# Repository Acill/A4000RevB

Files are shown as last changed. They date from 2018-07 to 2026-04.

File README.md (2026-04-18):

# A4000 Replica Project (Based on the Rev B)
Amiga 4000 Replica project. Based on the A4000 Rev B and organized by Paul Rezendes and the generous contributions of the Amiga Community. 

*** IF YOU WISH TO PRODUCE YOUR OWN BOARDS PLEASE USE THE NEW GERBERS LOCATED HERE: https://github.com/Acill/A4000RevB/tree/master/Gerbers-JLCPCB ***

ASCII (PADS) export has been added are are located into the ASCII folder. You can use this to import into other EDA applications. 

By popular request I have added the project into Kicad. its available in the Kicad folder. Please commit any change back here and document them. 

IF YOU PRODUCE BOARDS USING ORIGINAL PROJECT FILES YOU ***MUST*** TELL THE FACTORY TO IMPORT THE GERBERS AS A ***MENTOR PADS FORMAT PROJECT*** The gerbers located here are already good for use as JLCPCB. please read firther information in the gerber section. 

***Thank you Chucky for the locator build hosting! I recomend all go here during your builds for some great help!
A4000 Locator Site: http://locator.reamiga.info/locator.php?project=A4000***

***A4000 Build Guide, Thanks to Chucky! https://wordpress.hertell.nu/?p=1053***

***Shred made a great repo for an updated BOM. Thank you! Please visit the new BOM here: https://shred.github.io/a4000-bom/***

READ THIS: New board files and gerbers have been created and posted to the Github project page. A minor error was discovered that had solder mask covering the ground pads for the support bracket on the mouse and joystick ports. Previous boards work just fine and are not in danger of not working. This is more of a cosmetic update than anything else. Get the new file in the Gerber folder. When using the Chinese sites like JLPCB and PCBway you will need to upload the complete zip gerber archive and email them about the board design. It is done in Mentor PADs. This is a professional layout and it will not usually work with the automatic software they use. I have produced these here in the US and have no problems. Others have used JLPCB with no problems as well. I f you would like a single board and need help I can order sets of 5 and would be happy to sell you one. You can email me through the contact page or directly at info@acill.com and request one. Currently they run $95 shipped in the USA and $110 international.  

# Images
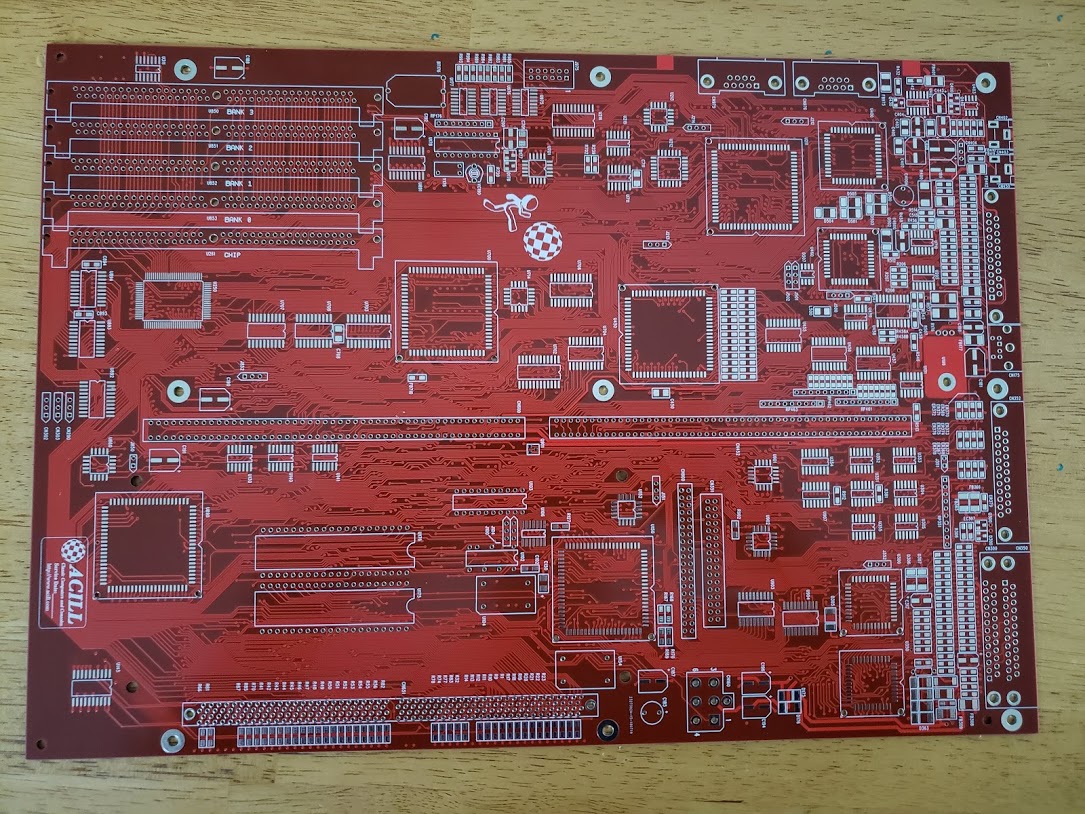
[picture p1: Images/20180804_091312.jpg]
 
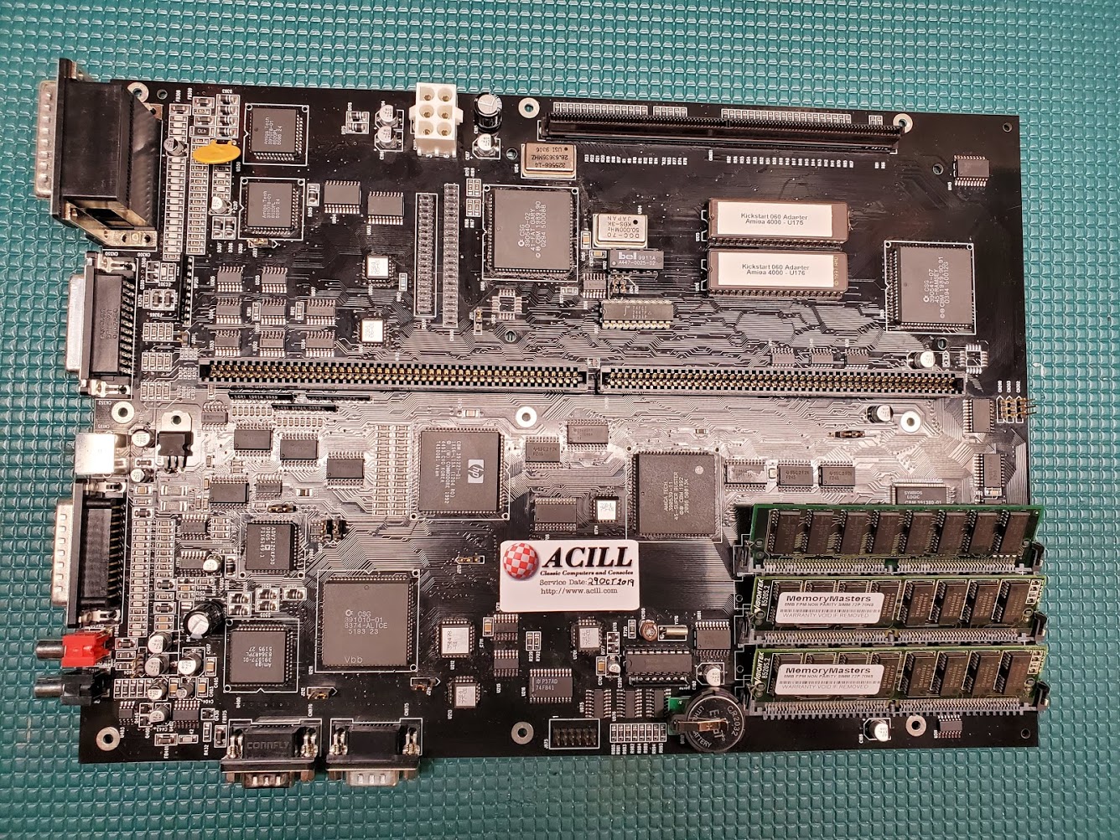
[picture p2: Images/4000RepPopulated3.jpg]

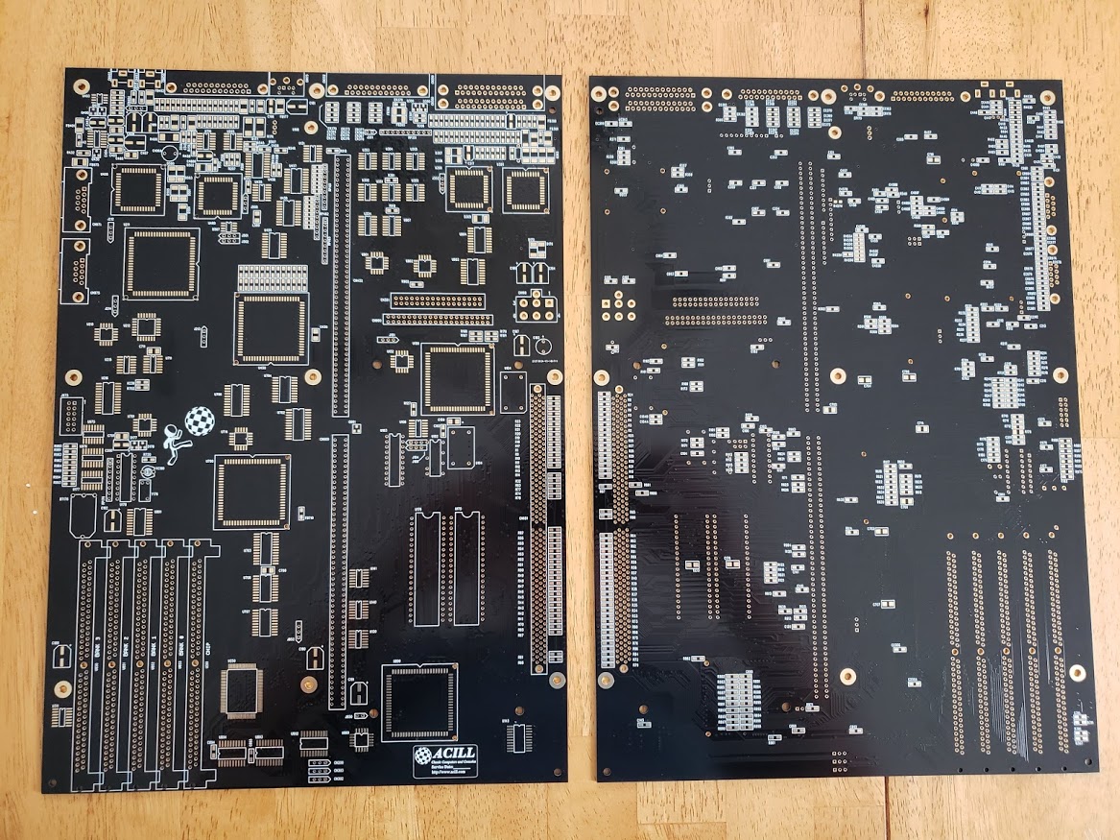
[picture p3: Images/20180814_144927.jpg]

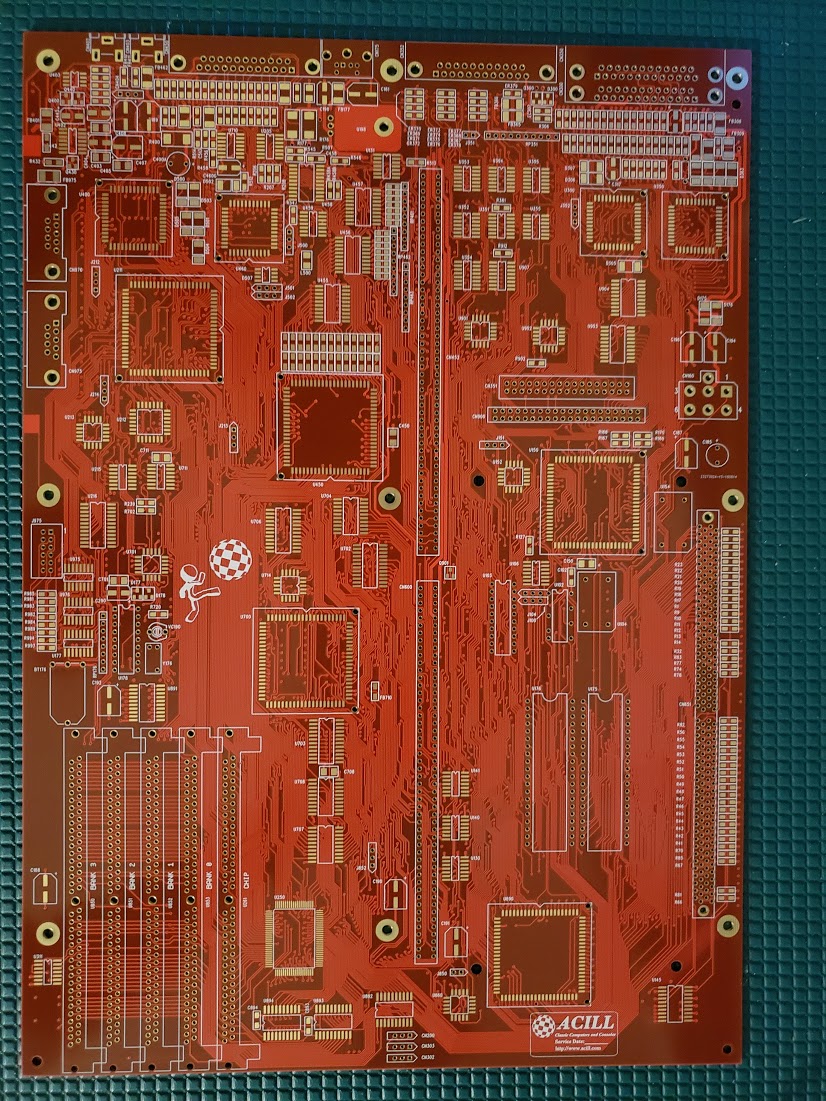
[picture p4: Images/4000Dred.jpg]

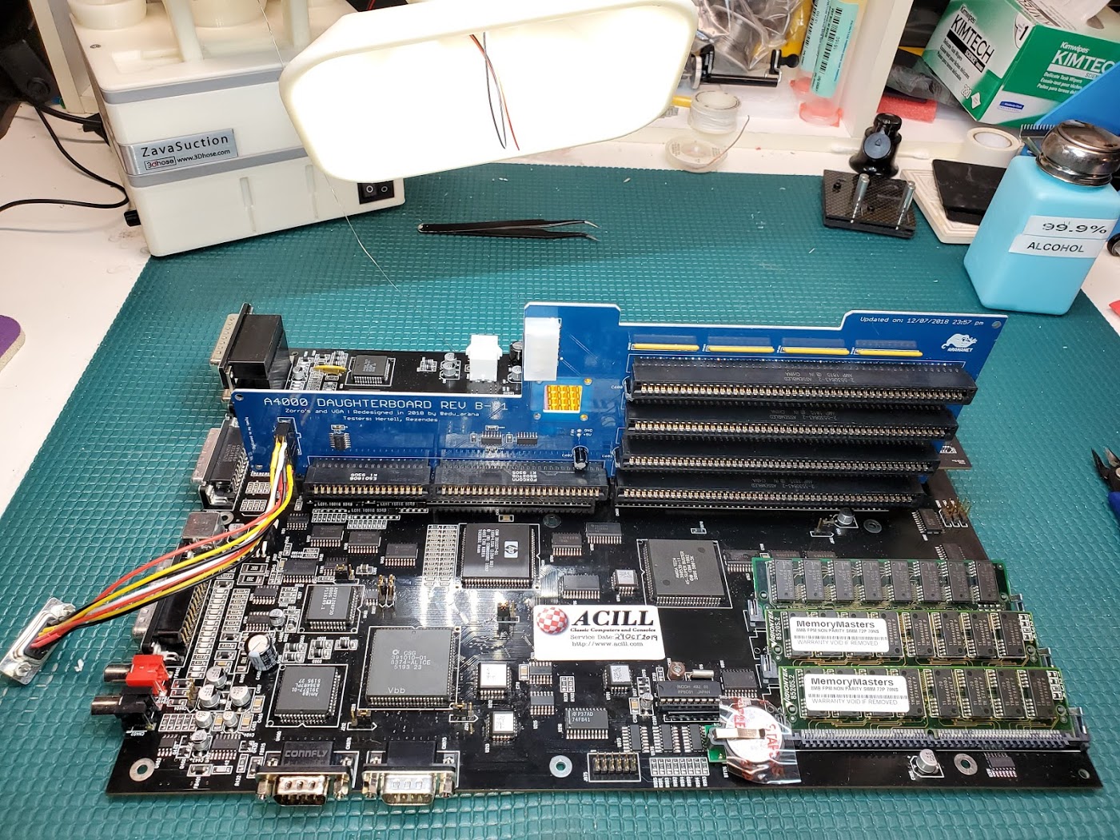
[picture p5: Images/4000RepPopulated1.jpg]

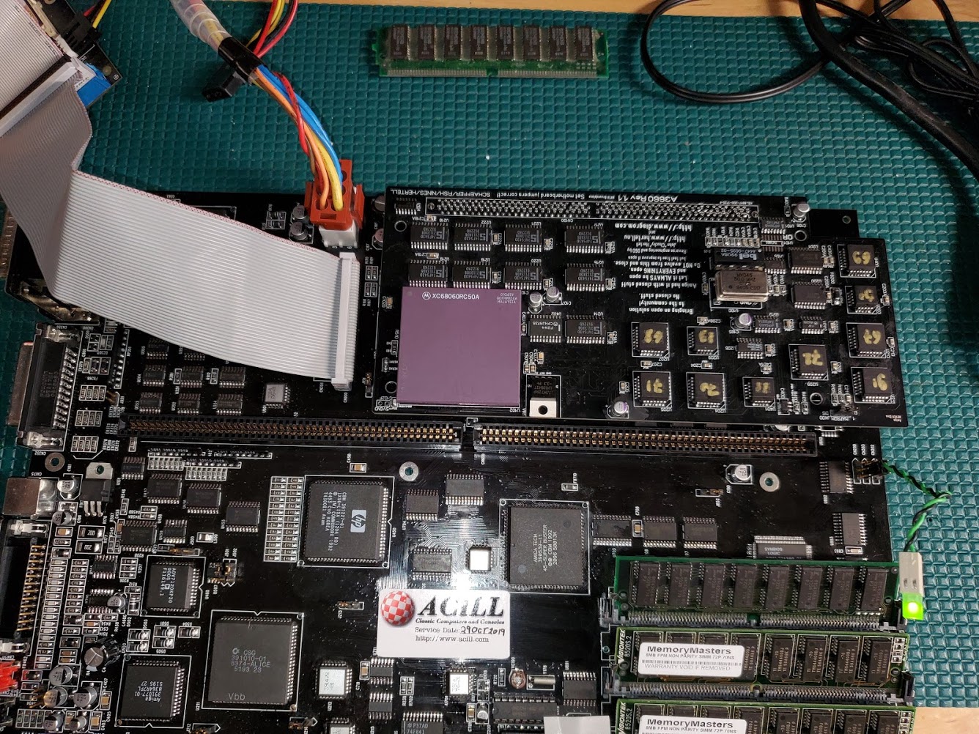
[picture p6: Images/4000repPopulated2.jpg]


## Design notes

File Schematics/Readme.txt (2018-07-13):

This is the final schematic without the electrical comparison test.
I fix the flag problems and found a few other problems that I have also fixed.  I have very high confidence in the schematic and netlist at this time. 
Schematic matches the PDF which also now matches the PCB.  There were some errors in the provided PCB.
There are 3 nets which are not connected, IO_CH_RDY, _LDS and _UDS.

I did not make any changes from the original design such as tying the unused logic gate inputs to ground.

FYI, this is a 4 layer board with mixed signal / planes for the inner layers.  They originally used the internal layers to make some of the signal connections in addition to power and ground planes.

Viewing requires Mentor Graphics PADS or the PADS free viewer! Final versions will be posted once the review is complete. 
THIS IS NOT A FEATURE REQUEST REVIEW! This is only to finalize the schematic for final board layout.

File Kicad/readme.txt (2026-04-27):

Its been a long over due wait, but here is the project in Kicad at last. Please continue to merge here and comment any updates. 

Project and schematics are together in the 7zip archive.

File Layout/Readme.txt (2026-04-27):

This is a Mentor Graphics PADs layout! If you want to use something else the ASCII exports are located in the ASCII folder. You can import them into for example Kicad or Altium. 

FINAL layout is attached PADS PCB database.
The design has been updated and follows the schematic netlist exactly.
To view the plane data go to 'Tools' and then the 'Pour Manager', 'Plane Connect' and pour all. 

This is similar to the original trace routing but I update to be more manufacturable.
The best I could do in regards to design rules, is with the majority of the board at 10mil traces and 8mil space.  Power and ground at 20mil.
Some areas have 6 mil spacing and 8 mil lines.
Unfortunately this was a poorly designed board in terms of maufacturability.  It should have been a 6 layer board.
The biggest issue is with the trace routing and trying to fit the large number of signal connections on only 2 layers.  
The original designers put traces between the pads of the SM resistors and capacitors, not generally a good idea.
Trace entry to pads was very poor with lots of 'acid traps'.
There were a few dead traces and extra vias.  At some point some of the vias may have been used as test points(?).

At least it is better than the original at this point.  I did not move the parts but cleaned the traces and changed via types.
I you want to make the board to IPC specifications at some point,  we would need to go to 6 layers and redefine most of the SM parts.

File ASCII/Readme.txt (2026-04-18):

PADS ASCII export. You can use this to import into other EDA applications such as Kicad, Altium and Easy EDA.

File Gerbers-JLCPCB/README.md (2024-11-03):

# Gerber Files with the New Silkscreens
Original Gerber files were created Using Mentor PADS application. When imported to most PCB production house websites, like JLCPCB.com, several layers are not shown correctly and will not be aligned to each other. I had a set of PCBs produced at JLC. They made the necessary adjustments and produced the boards correctly. As part of the process, they provided adjusted Gerber files. Those files are shown correctly when opened by any Gerber viewer. I imported those files into Kicad and completely redid the silkscreens on both sides.

Note that the Kicad files I created cannot be used to modify the copper and other production related layers as original component information is lost and all layers were converted to graphical elements.

As part of the production process, JLCPCB makes an adjustment to drill holes (slightly enlarge them). As we are using adjusted files, they should not do another adjustment on them. Make sure to add the note below as part of PCB remarks.

PCB Remark:
Drill layer was already compensated and optimized. Do not further modify drill layer values.

# Updated Pick and Place Files
I updated the BOM and CPL files to fix placement and rotation issues. Some of the parts are not available in JLCPCB stocks and must be ordered via Global Parts service. These orders usually take 2-3 weeks to arrive to your inventory at JLCPCB. Some parts are too expensive or not available even from GP service partners. These parts are not listed in the BOM file but they are still listed in the CPL file in case you wish to get them populated. As a result, when importing BOM/CPL files, you will get a warning about some missing parts in BOM file. Just accept and continue.

U700 (Super Buster) and U714 (GAL) sockets cannot be assembled at the same time as they have a slight conflict. I chose to get U700 socket populated by JLCPCB and slightly shave and hand solder U714 socket.

Some of the PLCC sockets show location pins when there is no hole for them on the PCB. JLCPCB PCBA team will ask you whether they should cut the pins of the PLCC socket at a cost. The part numbers I have in the BOM do not have those location pins, so there is nothing to cut. Give them this response and you will be fine. There is a PCBA remark box when ordering, but they ignored and asked me anyway.

PCBA Remark:
SMD PLCC sockets used in this project do not have placement pins. Ignore the holes or hole markers on the PCB for PLCC sockets and use pin 1 indicator on the silkscreen for the orientation of the sockets.

Kavanoz, May 2024

Preview of new Gerbers

Gerber-Viewer-Top

Gerber-Viewer-Bottom

Actual assembled PCB as produced by JLCPCB (There have been a slight update on the silkscreens after these were ordered)
Acill A4000D-Kavanoz-Top

Acill A4000D-Kavanoz-Bottom

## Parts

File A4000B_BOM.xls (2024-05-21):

BOM OCR and corrections by tbtorro (Jozsef Vamosi) based on A4000 Service Addendum
PCB Assembly, A4000D (364837 Rev B)
364837-01 | PCB Assembly, A4000 NTSC
364837-02 | PCB Assembly, A4000 PAL
364836-01 | Schematic
364838-01 | PCB Fab
364839-01 | Artwork
 | CAPACITORS |  | Package | No. Of parts
390818-01 | Capacitor, SM, MLC, NPO, 22pF (1206) | C485 C179 |  | 2
390818-04 | Capacitor, SM, MLC, NPO, 47pF (1206) | EC976-EC989 EC350-EC364 |  | 29
390818-05 | Capacitor, SM, MLC, NPO, 56pF (1206) | C178 |  | 1
390818-06 | Capacitor, SM, MLC, NPO, 100pF (1206) | EC182-EC184 EC300-EC309 EC365-EC379 EC410 EC411 EC451-EC464 |  | 44
390818-10 | Capacitor, SM, MLC, NPO, 330pF (1206) | C446, C447 |  | 2
390853-08 | Capacitor, SM, MLC, X7R, 3900pF (1206) | C432 C442 |  | 2
390853-09 | Capacitor, SM, MLC, X7R, 6800pF (1206) | C431 C441 |  | 2
390853-01 | Capacitor, SM, MLC, X7R, .01 uF (1206) | C104 C154B C186 C193 C195 C409 C460D C460E C460F |  | 9
390853-04 | Capacitor, SM, MLC, X7R, .047uF (1206) | C411-C414 C430 C440 |  | 6
310027-02 | Capacitor, SM, Ceramic, 0.1uF (1206) | C102 C103 C106 C130 C131 C140 C141 C145 C152 C154A C177 C201 C205 C211A C211B C211C C212 C213 C215 C216 C250A C250C C300 C305 C311 C350-C355 C400B C402A C402B C455-C459 C460A C460B C460C C500 C860 C890-C894 C901-C904 C907 C975 C976 C990 C511-C513 C455B C456B C457B C458B |  | 64
390797-02 | Capacitor, SM, Ceramic, Z5U, .22uF (1210) | C150 C175 C176 C199 C403 C405 C406 C450 C700-C704 C706-C708 C710 C711 C714 |  | 19
391097-06 | Capacitor, SM, Elec. Alum. 4.7uF 25V 'A' | C200 C404 |  | 2
391097-07 | Capacitor, SM, Elec. Alum. 10uF 25V 'C' | C460G |  | 1
391097-03 | Capacitor, SM, Elec. Alum. 22uF 16V 'C' | C198 C317 C318 C433 C443 |  | 5
391097-04 | Capacitor, SM, Elec. Alum. 47uF 16V 'D' | C187-C192 C194 C196 C407 C408 |  | 10
391097-01 | Capacitor, SM, Elec. Alum. 100uF 6.3V 'D' | C181 |  | 1
390101-03 | Capacitor, Elec. Alum. Radial 470uF 16V | C185 C400A |  | 2
251029-06 | Capacitor, Trimmer, Ceramic, 6.8-45pF | VC190 |  | 1
 | TRANSISTORS, DIODES, FER RITES
391121-01 | IC, SMD, NPN, Transistor, 2N3904 (SOT23) | Q300 Q901 |  | 2
391122-01 | IC, SMD, PNP, Transistor, 2N3906 (SOT23) | Q400 |  | 1
391145-01 | Transistor, SM, N-Channel JFET MMBF102L | Q430 Q440 |  | 2
391327-01 | Diode, SM, 1N4001 (MELF) | D175 D176 D305-D307 D360-D363, D500-D505 |  | 15
391129-01 | Diode, SMT, 1 N4148 (SOT23) | D177 D178 D300 |  | 3
391559-01 | Filter, Ferrite, SMT (1812) | FB177 FB308 FB309 FB364-FB366 FB401 FB462 FB463 FB464 FB476 FB478-FB480 FB975 |  | 15
391092-03 | Fitter, Ferrite, SMT (1206) | FB710 FB410 FB411 ER976-ER989 |  | 17
 | RESISTORS
391093-01 | Resistor, SM, 1W, 5%, 1 Ohm (2512) | R400 |  | 1
391093-07 | Resistor, SM, 1W, 5%, 20 Ohm (2512) | R176 R177 |  | 2
391093-04 | Resistor, SM, 1W, 5%, 47 Ohm (2512) | R383 |  | 1
310026-45 | Resistor, Chip, 1/8W, 5%, 1 Ohm (1206) | R403 R404 R465 |  | 3
310026-24 | Resistor, Chip, 1/8W, 5%, 120 Ohm (1206) | R311 |  | 1
310026-43 | Resistor, Chip, 1/8W, 5%, 33 Ohm (1206) | R104 R211 R231-R237 R240-R248 R881-R899 |  | 37
310026-01 | Resistor, Chip, 1/8W, 5%, 47 Ohm (1206) | R101-R103 R105 R106 R111 R112 R161 R162 R212-R218 R222 R223 R451 R458-R464 R500-R508 R513 R520-R543 R701-R704 ER175 R458A R458B R660 R661 ER176 ER300-ER307 ER350-ER363 ER367-ER379 ER453 ER458-ER461 ER475 R165-R170 |  | 117
391509-04 | Resistor, Chip, 1/10W, 5%, 47 Ohm (0805) | R455A, R455B R455C R455D R455E R455F R455G R455H R456A R456B R456C R456D R456E R456F R456G R456H R457A R457B R457C R457D R457E R457F R457G R457H |  | 24
310026-29 | Resistor Chip, 1/8W, 5%, 75 Ohm (1206) | R510-R512 |  | 3
310026-30 | Resistor, Chip, 1/8W, 5%, 220 Ohm (1206) | R301 R307 |  | 2
310026-21 | Resistor, Chip, 1/8W, 5%, 470 Ohm (1206) | R120-R122 R175 R178 R651 |  | 6
310026-56 | Resistor, Chip, 1/8W, 5%, 680 Ohm (1206) | R65 R66 |  | 2
310026-57 | Resistor, Chip, 1/8W, 5%, 750 Ohm (1206) | R430 R440 |  | 2
310026-07 | Resistor, Chip, 1/8W, 5%, 1.0K Ohm (1206) | R67 R68 R70-R73 R125-R128 R171-R173 R181 R182 R239 R249 R302 R371 R381 R382 R401 R402 R433 R434 R443 R444 R545-R548 R612-R626 R630-R635 R639 R708-R712 R720-R722 R861 R862 R911 R912 R975 |  | 66
310026-54 | Resistor, Chip, 1/8W, 5%, 1.2K Ohm (1206) | R79-R88 R179 R405 |  | 12
310026-51 | Resistor, Chip, 1/8W, 5%, 2.4K Ohm (1206) | R403D R403H |  | 2
310026-16 | Resistor, Chip, 1/8W, 5%, 2.7K Ohm (1206) | R1-R64 R74-R78 R206 R207 R407 R652 R871 R904 R905 |  | 76
310026-46 | Resistor, Chip, 1/8W, 5%, 3.3K Ohm (1206) | R151 R360 R361 |  | 3
310026-08 | Resistor, Chip, 1/8W, 5%, 4.7K Ohm (1206) | R515 R403C R403G R981-R994 |  | 17
310026-17 | Resistor, Chip, 1/8W, 5%, 10 K Ohm (1206) | R208 R305 R306 R406 R408 R431 R432 R441 R442 R457 R465 R514 R403A R403B R403E R403F R355-R359 |  | 21
310026-55 | Resistor, Chip, 1/8W, 5%, 11 K Ohm (1206) | R902 R903 |  | 2
310026-31 | Resistor, Chip, 1/8W, 5%, 100K Ohm (1206) | R180 |  | 1
310026-19 | Resistor, Chip, 1/8W, 5%, 470K Ohm (1206) | R435 R445 |  | 2
391154-27 | Resistor, Chip, 1/8W, 1%, 562 Ohm (1206) | R509 |  | 1
902412-14 | Res. Netwk., SIP, 9 Pin, 8 Element, 1K Ohm | RP461-RP463 |  | 3
902410-10 | Res. Netwk., SIP, 10 Pin, 9 Element, 1K Ohm | RP351 |  | 1
902442-35 | Res. Netwk., SIP, 8 Pin, 7 Element, 10K Ohm | RP176 |  | 1
325566-27 | Oscillator, 50 MHz, T.H. Can | U104 |  | 1
325566-14 | Oscillator, 28.63636 MHz, T.H. can | U154 (NTSC)
252344-01 | Oscillator, 28.37516 MHz, T.H.can | U154 (PAL) |  | 1
900560-01 | Crystal, 32.768 KHz, T.H. | Y176 |  | 1
 | INTEGRATED CIRCUITS
391513-02 | IC, Kickstart ROM (LOW) 150ns | U176 Set J151 = Pins 2-3 (V39.106) | DIP40 | 1
391514-02 | IC, Kickstart ROM (HIGH) 150ns | U175 Set J151 = Pins 2-3 (V39.106) | DIP40 | 1
391010-01 | IC, CSG, 8374, ALICE | U211 | PLCC84 | 1
391227-01 | IC, CSG, 4203, LISA | U450 | PLCC84 | 1
391077-01 | IC, 8364R7 PAULA | U400 | PLCC52 | 1
391078-02 | IC, SM, LSI, CIA 8520A-1 | U300 U350 | PLCC44 | 2
390525-01 | IC, Ricoh, Real Time Clock, RP5C01 | U178 | DIP18 | 1
391494-01 | IC, VideoDAC, Triple 8-BIT, ADV7120 | U460 | PLCC44 | 1
390540-02 | IC, LSI, FAT GARY, FOO8B | U150 | PLCC84 | 1
390541-07 | IC, FAT RAMSEY, F012G | U890 | PLCC84 | 1
391380-01 | IC, BRIDGETTE | U250 | PQFP100 | 1
390539-09 | IC, LSI, FAT BUSTER, F0131 | U700 | PLCC84 | 1
391473-01 | IC, SMD, Op Amp, Dual, LM833 | U403 | SOIC8N | 1
391103-01 | IC, SMD, Op Amp, Quad JFET, LF347 | U402 | SOIC14N | 1
390555-01 | Delay Line, 5 Tap, 25ns | U102 | DIP14 | 1
391087-01 | IC, SMD, Quad Line Driver, 1488 SOIC | U304 | SOIC14N | 1
391086-01 | IC, SMD, Quad Line Receiver, 1489 SOIC | U305 | SOIC14N | 1
391421-01 | Voltage Reference, 1.2V, SO-8 | D507 | SOIC8N | 1
901527-03 | IC, Voltage Regulator, Fixed Output, 7905 | U198 | TO220 | 1
391554-01 | IC, Linear, LF347, EIAJ Package | Sub for PN 391103-01
391478-01 | IC, PAL 22V10-10 CAS Gen Content: 391392-03 | U212 | PLCC28 | 1
391477-01 | IC, PAL, 16L8-10 Chip RAM Ctrl Content: 391412-01 | U213 | PLCC20 | 1
391476-01 | IC, PAL, 16R4-15 Arb & int. Content: 391359-04 | U701 | PLCC20 | 1
391475-01 | IC, PAL, 16L8-10 Zorro Decode Content: 391199-03 | U714 | PLCC20 | 1
391406-01 | IC, PAL, 16L8-15 IDE Decode Content: 391199-04 | U901 | PLCC20 | 1
391405-01 | IC, PAL, 16R6-15 Programmed PLCC20, IDE state Content: 391403-02 | U902 | PLCC20 | 1
391276-01 | 7406, SOIC package | U131 | SOIC14N | 1
391188-01 | 7407, SOIC package | U311 U141 | SOIC14N | 2
391499-01 | 74F521, SOIC package | U145 | SOIC20W | 1
391088-01 | 74F04, SOIC package | U215 | SOIC14N | 1
391183-01 | 74F08, SOIC package | U130 U710 | SOIC14N | 2
391175-01 | 74F32, SOIC package | U140 | SOIC14N | 1
391320-01 | 74F74, SOIC package | U106 U459 | SOIC14N | 2
391325-01 | 74F86, SOIC package | U711 | SOIC14N | 1
391375-01 | 74F245, SOIC package | U704 U707 U708 U891-U894 | SOIC20W | 7
391481-01 | 74F841, SOIC package | U216 | SOIC24W | 1
391374-02 | 74FCT646T, SOIC package | U702 U703 U706 | SOIC24W | 3
391480-01 | 74HCT166, SOIC package | U975 U976 | SOIC16N | 2
391400-01 | 74FCT244T DIP package | U103 | DIP20 | 1
391474-01 | 74FCT245T, SOIC package | U455-U458 | SOIC20W | 4
391377-01 | 74HCT174, SOIC package | U177 U354 U907 | SOIC16N | 3
391326-01 | 74LS38, SOIC package | U352 | SOIC14N | 1
391141-01 | 74LS74A, SOIC package | U351 | SOIC14N | 1
391311-01 | 74HC4066, SOIC package | U205 | SOIC14N | 1
391100-01 | 74HCT245, SOIC package | U903 U904 | SOIC20W | 2
391191-01 | 74LS125A, SOIC package | U353 U355 | SOIC14N | 2
391548-01 | 74F86, SM, EIAJ package | Substitute for PN 391325-01
391552-01 | 74HCT174, SM, EIAJ Package | Substitute for PN 391377-01
391555-01 | 74LS74A, SM, TTL, EIAJ Package | Substitute for PN 391141-01
 | SOCKETS
390768-04 | Socket, 20 Pin .3 DIP20 machine pin | U103 |  | 1
904150-06 | Socket, 40 Pin .6 DIP40 | U175 U176 |  | 2
391368-01 | Socket, 72 Pin 22.5 Deg. SIMM | U261 U850-U853 |  | 5
390719-01 | Socket, single pin (.040 hole) or DIP14 machine pin | U104 U154 |  | 2
 | MISC ELECTRICAL
380393-02 | Battery, NICAD, Rechargeable, 3.6V | BT176 |  | 1
390924-01 | Varistor Switch, Self Resetting 1.85A | F 175 |  | 1
 | CONNECTORS
903345-06 | 12 DIL .1" x .1' Header | J975 |  | 1
903345-17 | 34 DIL .1' x .1" Header | CN351 |  | 1
903345-20 | 40 DIL .1" x .1" Header | CN900 |  | 1
903326-02 | 2 x .1" SIL | J351 J850 |  | 2
903326-03 | 3 x .1" SIL | CN404 J100 J104 J151 J212-J214 J352 J500-J502 J852 CN200 CN302 CN303 |  | 15
390242-01 | DB9 Male | CN975 CN976 |  | 2
390242-03 | DB23 Male | CN450 |  | 1
390241-03 | DB23 Female | CN352 |  | 1
390625-04 | Stacked DB25 Male/Female (missionary) | CN350+CN300 |  | 1
390851-04 | 6 Pin MINI DIN, Female | CN175 |  | 1
390043-01 | Shorting Bars (Shunts) | J100 J104 J120 J151 J152 J212 J214 J352 J850 J852 |  | 10
903349-01 | 6 Pin Connector (Power In) | CN160 |  | 1
252122-02 | RCA Jack (Red) | CN403 |  | 1
252122-01 | RCA Jack (White) | CN402 |  | 1
903446-06 | 100 Pin Edge Card Connector | CN452 CN600 |  | 2
390557-01 | 200 Pin KEL200 Female/Receptacle Conn. | CN651 |  | 1
 | BLANK COMPONENTS
 | L500
 | C406H
 | Total no. Of parts |  |  | 788
 | Number of trough hole parts about 30pcs

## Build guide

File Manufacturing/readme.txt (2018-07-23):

This is the manufacturing data needed for pick and place and other required files for various manufacturing processess. 
These are not required for most fabs to just produce boards, but is very usefull for larger scale orders if users wanted it done.

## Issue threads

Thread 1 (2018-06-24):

A4000RevB schematic feedback

mrand, 2018-06-24:
I saw the request for review and had a few minutes to fly through the schematic.  I didn't review much of the logic, so hopefully someone else is doing that.

I haven't looked at the 74F08 and HC logic datasheets in a while,  but I'd suggest tying both inputs off, not just one input of each gate (U130-A, -C, and -D).  U177.13 and .14 as well as U215-D and U907-A.   And maybe the inputs to U459-B.

And when you do, you might consider tying off all the logic gates with pull resistors so that you can more easily use that gate in case of emergency rather than dead-bugging a gate somewhere, or having to lift a pin.

Is there a way to do a cross-reference (typically used to add page numbers to off page flags)?  That would help you verify that you don't have any nets mis-named or mis-connected.

There are a few comments, including most especially on page 13, that make it seem like some follow-up work might be needed.

Nice work!

Acill, 2018-06-25:
Thanks for the comments! I have submitted this to the company doing the design work.

Acill, 2024-05-21:
Schematics are in what I feel are the final and most closely representing the final production version of the A4000. Many improvements have been done as well to clean up some silly decisions made by the original design.

Closed 2024-05-21.

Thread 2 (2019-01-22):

ADV7120 does not get 5V VAA

ishe, 2019-01-22:
I have built the A4000 with this motherboard and have noticed a serious issue. The picture on the monitor was too dark when I used the RGB signals (indeed I was lucky to see anything). It turned out that the ADV7120 does not get 5v to its VAA pins. Troubleshooting it I have noticed that L500 inductor is connected to nowhere. It seems the layout is incorrect and ADV7120 does not get 5v input! L500 should be connected to 5v and to AVID+. This is missing from the PCB so L500 is isolated and useless.

Acill, 2019-01-23:
Where did you get your board from? I have built several of these now as
well as several other people without finding this issue.

On Wed, Jan 23, 2019 at 12:30 AM Istvan Hegedus <notifications@github.com>
wrote:

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

Acill, 2019-01-23:
Where did you get the board you used from. Was it one of mine? Several people have built them now as well as the 4 I have done myself without finding this issue. All are working just fine.

ishe, 2019-01-23:
Hi,
I have bought it from you via ebay. But I am 100% sure all your boards
don't have the L500 connected to anywhere. I have checked the schematic on
Github and L500 is left unconnected in the schematic! The reason why others
did not have issue is that they have installed R465 (1 ohm). I however did
not install it at first because original boards did not have it either.
Also amigapcb.org has L500 connected to null signals. It is weird why.
Istvan

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

ishe, 2019-01-24:
I have used both locators, amigapcb.org and John Hertell's locator to build. I don't have original board to verify, but from the photos on the net what I can see is that L500 has 2 vias going to probably to vcc layer and to other side. On the photos (big book of Amiga HW) R465 is not installed. Also the BOM on github says for R465 that it is a blank component (number of 1ohm 1206 resistors is only 2). Using this motherboard L500 is useless and should be removed from BOM.
In some other forums at least one person mentions that he has 10k resistor on R465 which obviously not a good choice if there is no L500. Other person has measured voltages on L500 and it was 4.95v so I am sure on some boards L500 should be active.

Acill, 2019-01-24:
I will look more into this then.

On Thu, Jan 24, 2019 at 1:30 AM Istvan Hegedus <notifications@github.com>
wrote:

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

Acill, 2019-01-25:
Looking more into this  If you're going to fit a 1 ohm resistor at R465, then dont bother installing L500. With L500 installed you shouldnt need R465. This is shown on the original Commodore schematic as well and dont understand why they have used both, but being a clone i just followed it.

ishe, 2019-01-27:
Yes, that is true. Probably L500 was planned to filter PSU noise. It works
fine with R465 as 1 ohm. Other parts of the PCB seem to be ok. I have built
it and works fine with an A3660 CPU card!

2019. jan. 25., Pén 19:40 dátummal Acill <notifications@github.com> ezt
írta:

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

johntayloruk, 2020-06-09:
Hi, I know this is old now, but I’ve just spent the entire day trying to identify why my new build wasn’t working.  It’s only when I caught glimpse of something on screen that I turned the brightness up on my monitor that i saw a very faint display.  I’ve checked all components related to the video output and the come across this thread.

I have put the fixed inductor in L500 and a 10k resistor at R465 as per the BOM.

Are you saying I need to remove the 10k resistor at R465 and replace it with a 1 ohm resistor and it will work??  Do I need to remove the L500 top or is it ok there with the 1 ohm resistor?

ishe, 2020-06-10:
Hi,

There is no point in installing L500 to its place on the motherboard as
this replica does not have that connected at all. If you check traces it is
just a copper island, so it does not play a role.
Instead I recommend to go on the bottom of the motherboard and either
install 1 ohm to R465 or install the inductor to R465 which was supposed to
be installed on L500. I have tried both and it works fine. I have left the
inductor there.
Without these the ADV7120 does not get the 5v supply thus your screen is
very dark.

Br
Istvan

On Wed, Jun 10, 2020 at 1:24 AM johntayloruk <notifications@github.com>
wrote:

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

johntayloruk, 2020-06-10:
Just added the 1ohm resistor and it works!! Thank goodness I came across your issue, I haven't seen it mentioned anywhere else and my orig A4000 has nothing at R465.
Very happy now! :)
Thank You!

ishe, 2020-06-10:
I am glad I could help you! Your original A4000 must have L500 in its place
and that is the reason why it works without R465. On that motherboard L500
trace is connected and provides the 5v to ADV7120 via that thus R465 is not
needed there.
Best Regards
Istvan

On Wed, Jun 10, 2020 at 10:09 AM johntayloruk <notifications@github.com>
wrote:

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

Acill, 2020-06-18:
Put them 1Ohm in and see if it works.. I think it should. If not remove
L500.

On Tue, Jun 9, 2020 at 4:24 PM johntayloruk <notifications@github.com>
wrote:

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

saft6luck, 2024-02-06:
> Put them 1Ohm in and see if it works.. I think it should. If not remove L500.

So, in Jan2019 version, L500 is not connected at all. Only R465 can be used.

Acill, 2024-05-21:
New gerbers are clearly marked not to populate this component and to use a 1Ohm in place in the new silkscreen.

Closed 2024-05-21.

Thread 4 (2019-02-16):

Images

lorenko, 2019-02-16:
Can you post a fully populated hires top view? It can help for find and orienting materials.
thanks

Acill, 2020-01-13:
Done, sorry it has taken so long.

lorenko, 2020-01-13:
Thank you ;)

Acill, 2024-05-21:
New images posted in both Gerbers and main folders.

Closed 2024-05-21.

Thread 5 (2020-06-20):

Gerber problems...

JensRestemeier, 2020-06-20:
I'm not having much luck using the Gerber files.  (a4k-6x_pads_Jan2019.zip)
GERBV shows one layer (ASB) mirrored, most layers offset from each other.
The Gerber viewer in KiCad shows the top silkscreen layer offset from the rest.

I tried uploading it to a few board houses to get a quote, but they all seem to error out. Renaming the layers to the recommended names, for example from OSHPARK (https://docs.oshpark.com/troubleshooting/naming-pattern/ ) and deleting extra files still fails because of a missing board outline.

Obviously some people get boards manufactured, so is there a board house that has success with these files? Do they need to be converted somehow?

Acill, 2020-06-21:
These are in PADS format. I have been using a place in the US to do it, but
any reputable board house should have no problem with these. I have heard
even  https://jlcpcb.com/ has done them.

On Sat, Jun 20, 2020 at 3:34 PM Jens Ch. Restemeier <
notifications@github.com> wrote:

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

Acill, 2020-06-21:
Use this viewer:  https://www.pads.com/downloads/pads-pcb-viewer/

On Sun, Jun 21, 2020 at 12:21 AM Paul Rezendes <paul.rezendes@gmail.com>
wrote:

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

johntayloruk, 2020-06-21:
I’ve just had a bunch of A3660 boards made through https://jlcpcb.com/ And has no problems.  Easy to upload the gerbers and get a quote, fast build, delivery and reasonable price too.

JensRestemeier, 2020-06-21:
JLCPCB is the place I usually use for my PCBs, and I was trying to get a whole set of motherboard, daughter board and A3660 board.

The zip file from Chucky uploads fine, displays a preview and gives a quote.

The Gerber zip file from https://github.com/arananet/A4000db/tree/master/version1.2 previews fine in the KiCad Gerber viewer, but doesn't display anything or updates a quote on jlcpcb.

The Gerber zip file from https://github.com/Acill/A4000RevB/blob/master/Gerbers/a4k-6x_pads_Jan2019.zip shows misaligned layers in KiCad and Gerbv, and a mirrored layer in Gerbv. It doesn't display anything or updates the quote on jlcpcb.

I tried PCBWAY, JLCPCB and OSHPARK. OSHPARK gave me a quote for the daughter board after I renamed layers to match their naming pattern, it didn't work with the motherboard Gerbers. I didn't try any other company that requires an email registration before doing anything.

If people had success with JLCPCB in the past I'll contact their support, in case a recent software update on their side broke their import pipeline.

JensRestemeier, 2020-06-22:
I heard back from JLCPCB support, they think the upload problems are because of the file size, and they may work OK.
They pointed out that a4k-6x_pads_Jan2019.zip has no independent outline layer, is it possible to generate that in Pads?
(It makes me a bit nervous to order large boards without checking that the files uploaded correctly into the system, but if other people had success I'm willing to give it a try...)

kavanoz64, 2024-05-15:
I uploaded new Gerber and pick and place files. These work fine with JLCPCB and should work with other PCB houses too.

Closed 2020-06-21.

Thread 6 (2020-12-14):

Gerber files

AmigaPapst, 2020-12-14:
hello,

we would like to use the gerber files. But they does't work in Kicat. Can you help?

Best regards
Simon

Acill, 2020-12-14:
These gerbers are made using Mentor Graphics PADS. They work find for
manufacturing boards as long as you mention that to the board house you
use. I have had many made using them. I don't have knowledge of other CAD
software and use PADs.

-Paul

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

AmigaPapst, 2020-12-14:
Thanks for your fast reply. I have problems to view the gerber files with gerber viewer software. We see a offset of different layer. Which files are need to produce the boards?

AmigaPapst, 2020-12-14:
The top silk screen .SST has a offset of x and y coordinates compare to copper layers. The bottom silk screen .ssb fits perfectly.

AmigaPapst, 2020-12-14:
drill file (*.drd) has a y offset of 2,54 mm.

AmigaPapst, 2020-12-14:
The following layer are fits perfectly aligned on top:
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

AmigaPapst, 2020-12-14:
The following layer are doesn't fits perfectly aligned on top:
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

AmigaPapst, 2020-12-14:
They have the same problems: https://community.sw.siemens.com/s/question/0D54O00006eo69e/output-gerber-files-are-not-aligned

AmigaPapst, 2020-12-14:
This is a example manual how to export gerber files from PADS.
https://docs.oshpark.com/design-tools/mentor-graphics-pads/

Acill, 2020-12-17:
a4k-6x_pads_Jan2019.zip
<https://github.com/Acill/A4000RevB/blob/master/Gerbers/a4k-6x_pads_Jan2019.zip>
is the complete gerber you should be sending to a board house to get boards
made and tell them its in mentor Graphics PADS format.  These are from
professional board cad software, not open source like Kicad and cant be
read by them. If you want to view them you can use the PADs viewer for
free. Its located here: https://www.pads.com/downloads/pads-pcb-viewer/

You can open the project layout files for complete viewing as well. That
file is : a4k-4x_pads_FINAL.pcb
<https://github.com/Acill/A4000RevB/blob/master/Layout/a4k-4x_pads_FINAL.pcb>

Here are direct links from my github project page

Project layout file: https://github.com/Acill/A4000RevB/tree/master/Layout
Gerbers: https://github.com/Acill/A4000RevB/tree/master/Gerbers

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

Acill, 2020-12-17:
I have produced hundreds of these boards with no issues using the export
file I provided you. If you are using one from another source I cant help
you. Others have also been able to produce working boards suck as john
hertell in Sweden. Whoever you are using to make them is clearly doing
something wrong if they cant figure it out.

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

Acill, 2020-12-17:
Seems fine here?

[image: image.png]

On Thu, Dec 17, 2020 at 6:44 AM Paul Rezendes <paul.rezendes@gmail.com>
wrote:

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

AmigaPapst, 2021-01-17:
Thanks for your help. We produce the board. 👍

The-Real-G-Evil, 2022-08-06:
Hello Acill

Where did you produce your boards?

I want JLCPCB to produce them and they ask for the layer names.
Can you tell me what to select?

Regards Tim

Acill, 2022-08-06:
The auto tool won’t work. Upload the complete Berber zip and tell them the
format is mentor pads. John Hertell has used them and has no problems  with
them.

On Sat, Aug 6, 2022 at 12:43 PM The-Real-G-Evil ***@***.***>
wrote:

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

kavanoz64, 2024-05-15:
I uploaded new Gerber and pick and place files. These work fine with JLCPCB and should work with other PCB houses too.

Acill, 2024-05-15:
I just merged it. Thanks!

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

AmigaPapst, 2024-05-15:
Hello Acill,

thanks for you message and for merging. ;)

Best regards
Simon

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
Kind Regards
--
<sb>
Alinea Computer
Torsten Hees & Simon Neumann GbR
Amiga-Softwareentwicklung, Vertrieb und Online-Shop

Geschwister-Scholl-Str. 26
61273 Wehrheim
Deutschland

Tel.: +49 (0) (60 81) 5 76 99 88
(Zeiten: Mo bis Fr von 18 bis 19 Uhr, Sa von 11 bis 12 Uhr)

Internet-Seite: http://www.alinea-computer.de
Online-Shop: http://www.amiga-shop.net
Facebook: http://www.facebook.com/alineacomputer

Closed 2024-05-21.

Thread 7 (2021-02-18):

PCB Specifications?

shred, 2021-02-18:
I'm not an expert about PCB production. I tried to calculate the price at pcbway, but after uploading the Gerber files, I was confronted with questions about PCB specifications, like the number of layers, the individual layer names, thickness, min hole size, surface finish, via process, etc.

Can you give the "musts" and also some recommendations in the README that would give a good result?

Thank you!

Acill, 2021-02-18:
Its a 4 layer board and you need to email them the the zip file and tell
them its gerber output fron Mentor Graphics PADs.

-Paul

On Thu, Feb 18, 2021 at 8:56 AM Richard Körber <notifications@github.com>
wrote:

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

shred, 2021-02-18:
Even if I would send the zip file by mail, I guess they still want to know about thickness, surface finishing etc. What I mean is: It would be easier for noobs like me to produce "cheap" replica PCBs if I can just upload the ZIP file in their quick order tool, pick some options like recommended in the README, and then place the order and be done with it.

Well, I tried their Gerber viewer and ran into issue #6, so it probably won't work with pcbway anyway.

Acill, 2021-03-03:
Many people have had these made at those places with no problems. Its all
standard specs. Finish is up to you, most recommend Enig. If you use a PCB
viewer use the free one from Mentor PADS.

On Thu, Feb 18, 2021 at 10:25 AM Richard Körber <notifications@github.com>
wrote:

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

Acill, 2021-03-03:
Here is an order from JLPCB I made to see how they worked out. The boards
are not bad from them, but I honestly dont trust the China fabs.
[image: image.png]

MAybe if you email them and give them this order number Order Number:
Y5-2327302A you can get them to make them. I ordered 5 boards and it cost
me $360, so its still not cheap with the shipping.

On Wed, Mar 3, 2021 at 6:54 AM Paul Rezendes <paul.rezendes@gmail.com>
wrote:

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

shred, 2021-03-16:
Thank you for your help! Yes, it's not cheap. As I don't know much about PCB making, it was too risky for me to get five nice wall decorations because I made a mistake somewhere. I found a reseller of your PCB, so I just ordered one in the meantime.

However it's good that it is now documented somewhere.

Closed 2021-03-16.

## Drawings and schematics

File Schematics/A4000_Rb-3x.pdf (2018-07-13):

# A4000 Rb

# CLOCKS AND LOGIC

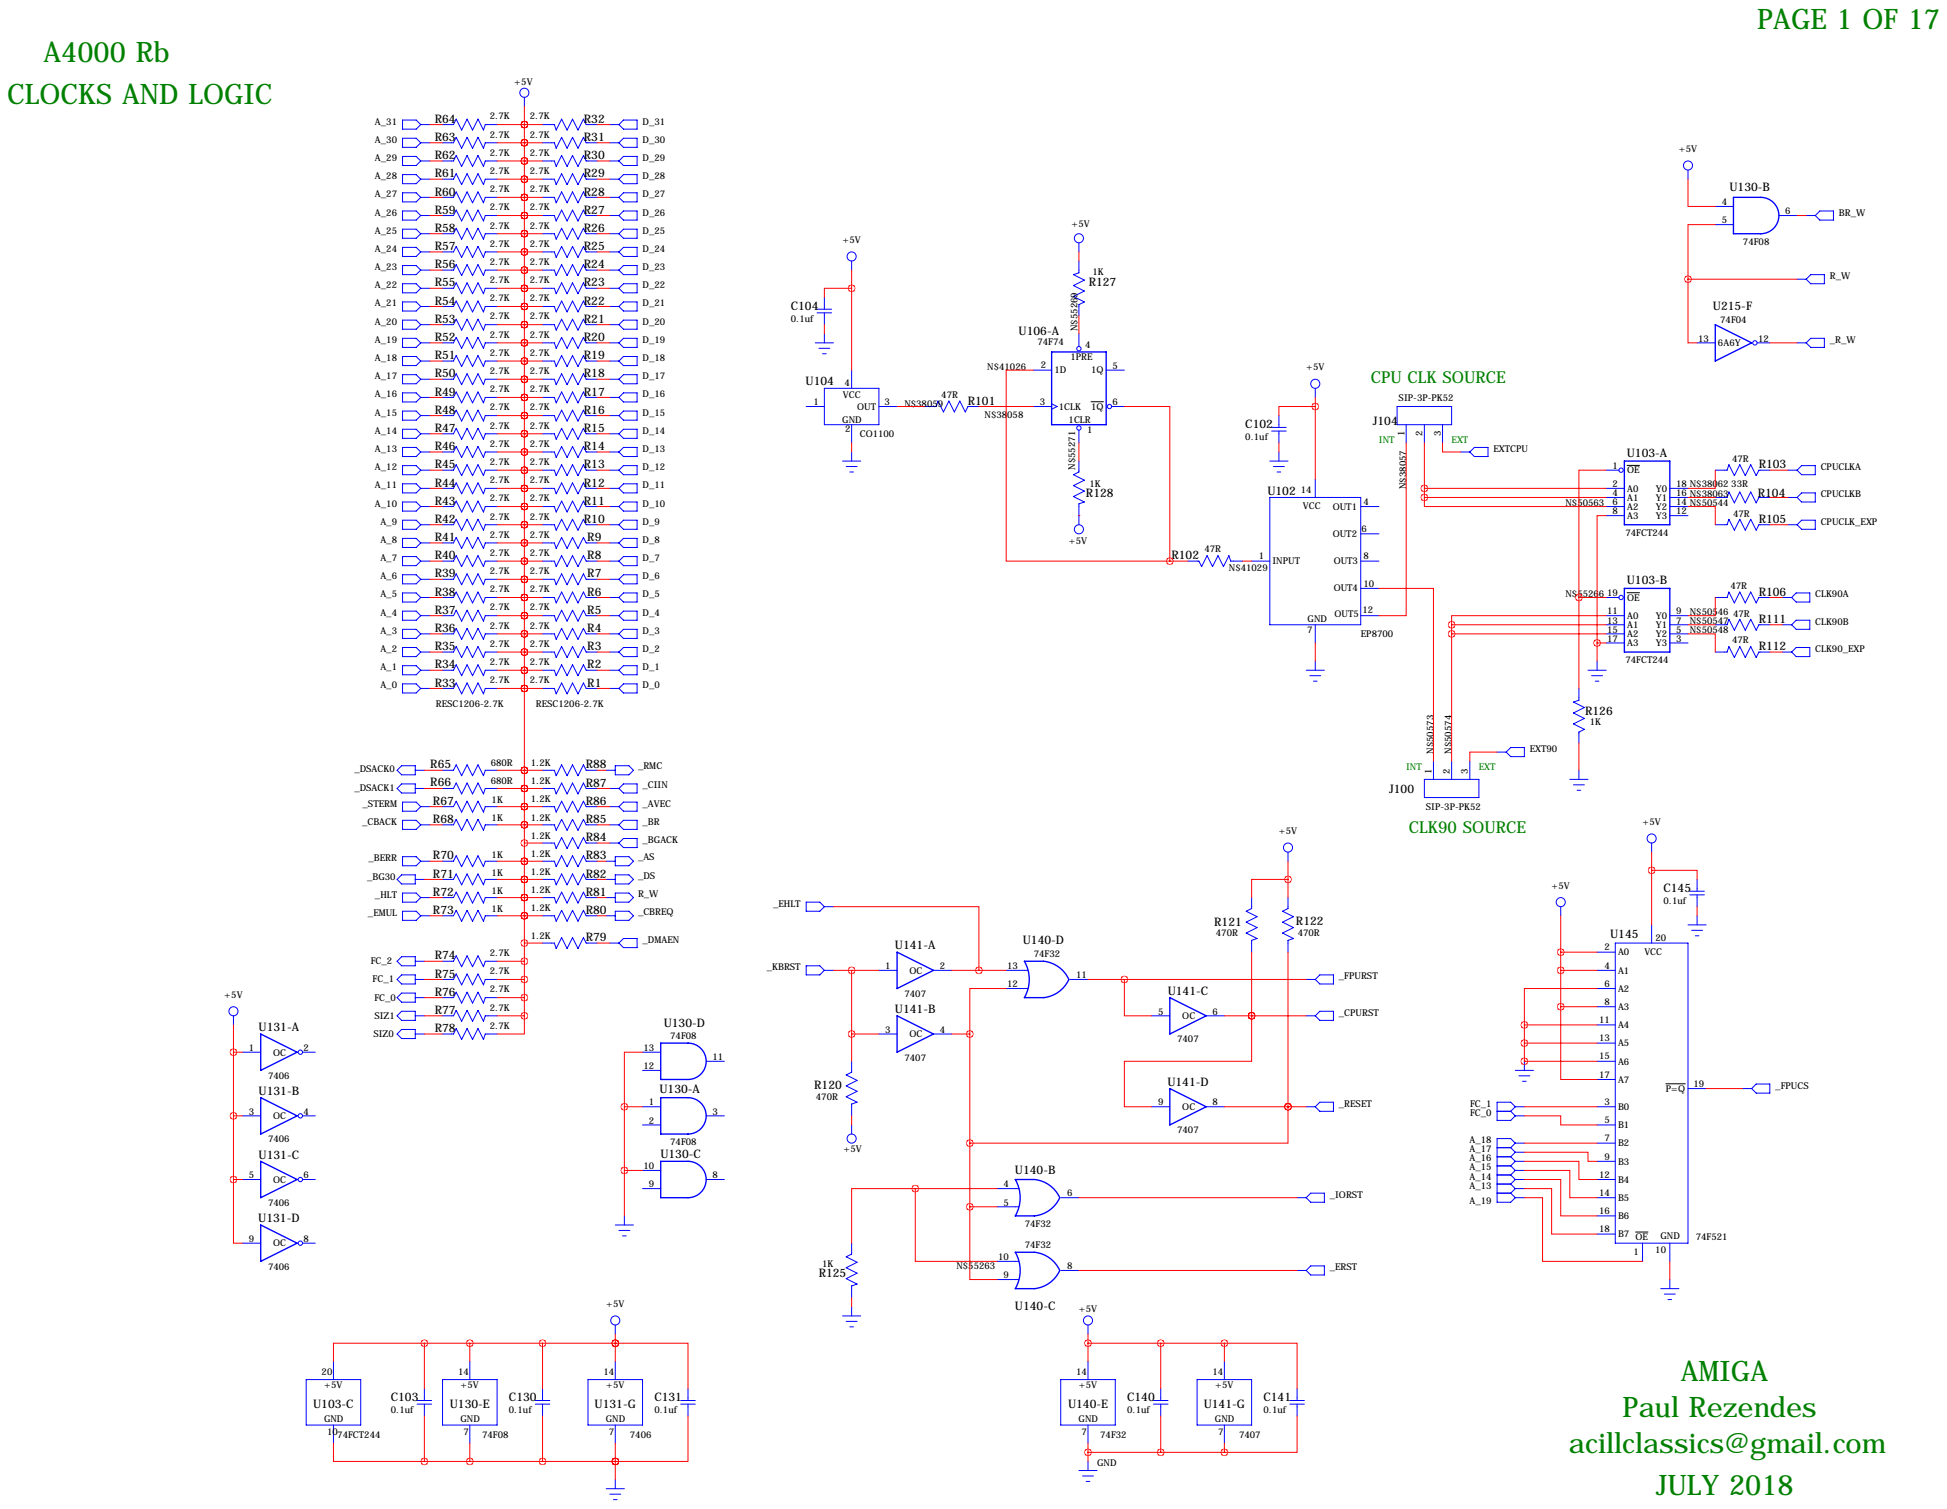
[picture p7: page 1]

# FAT GARY, ROM

U106-B

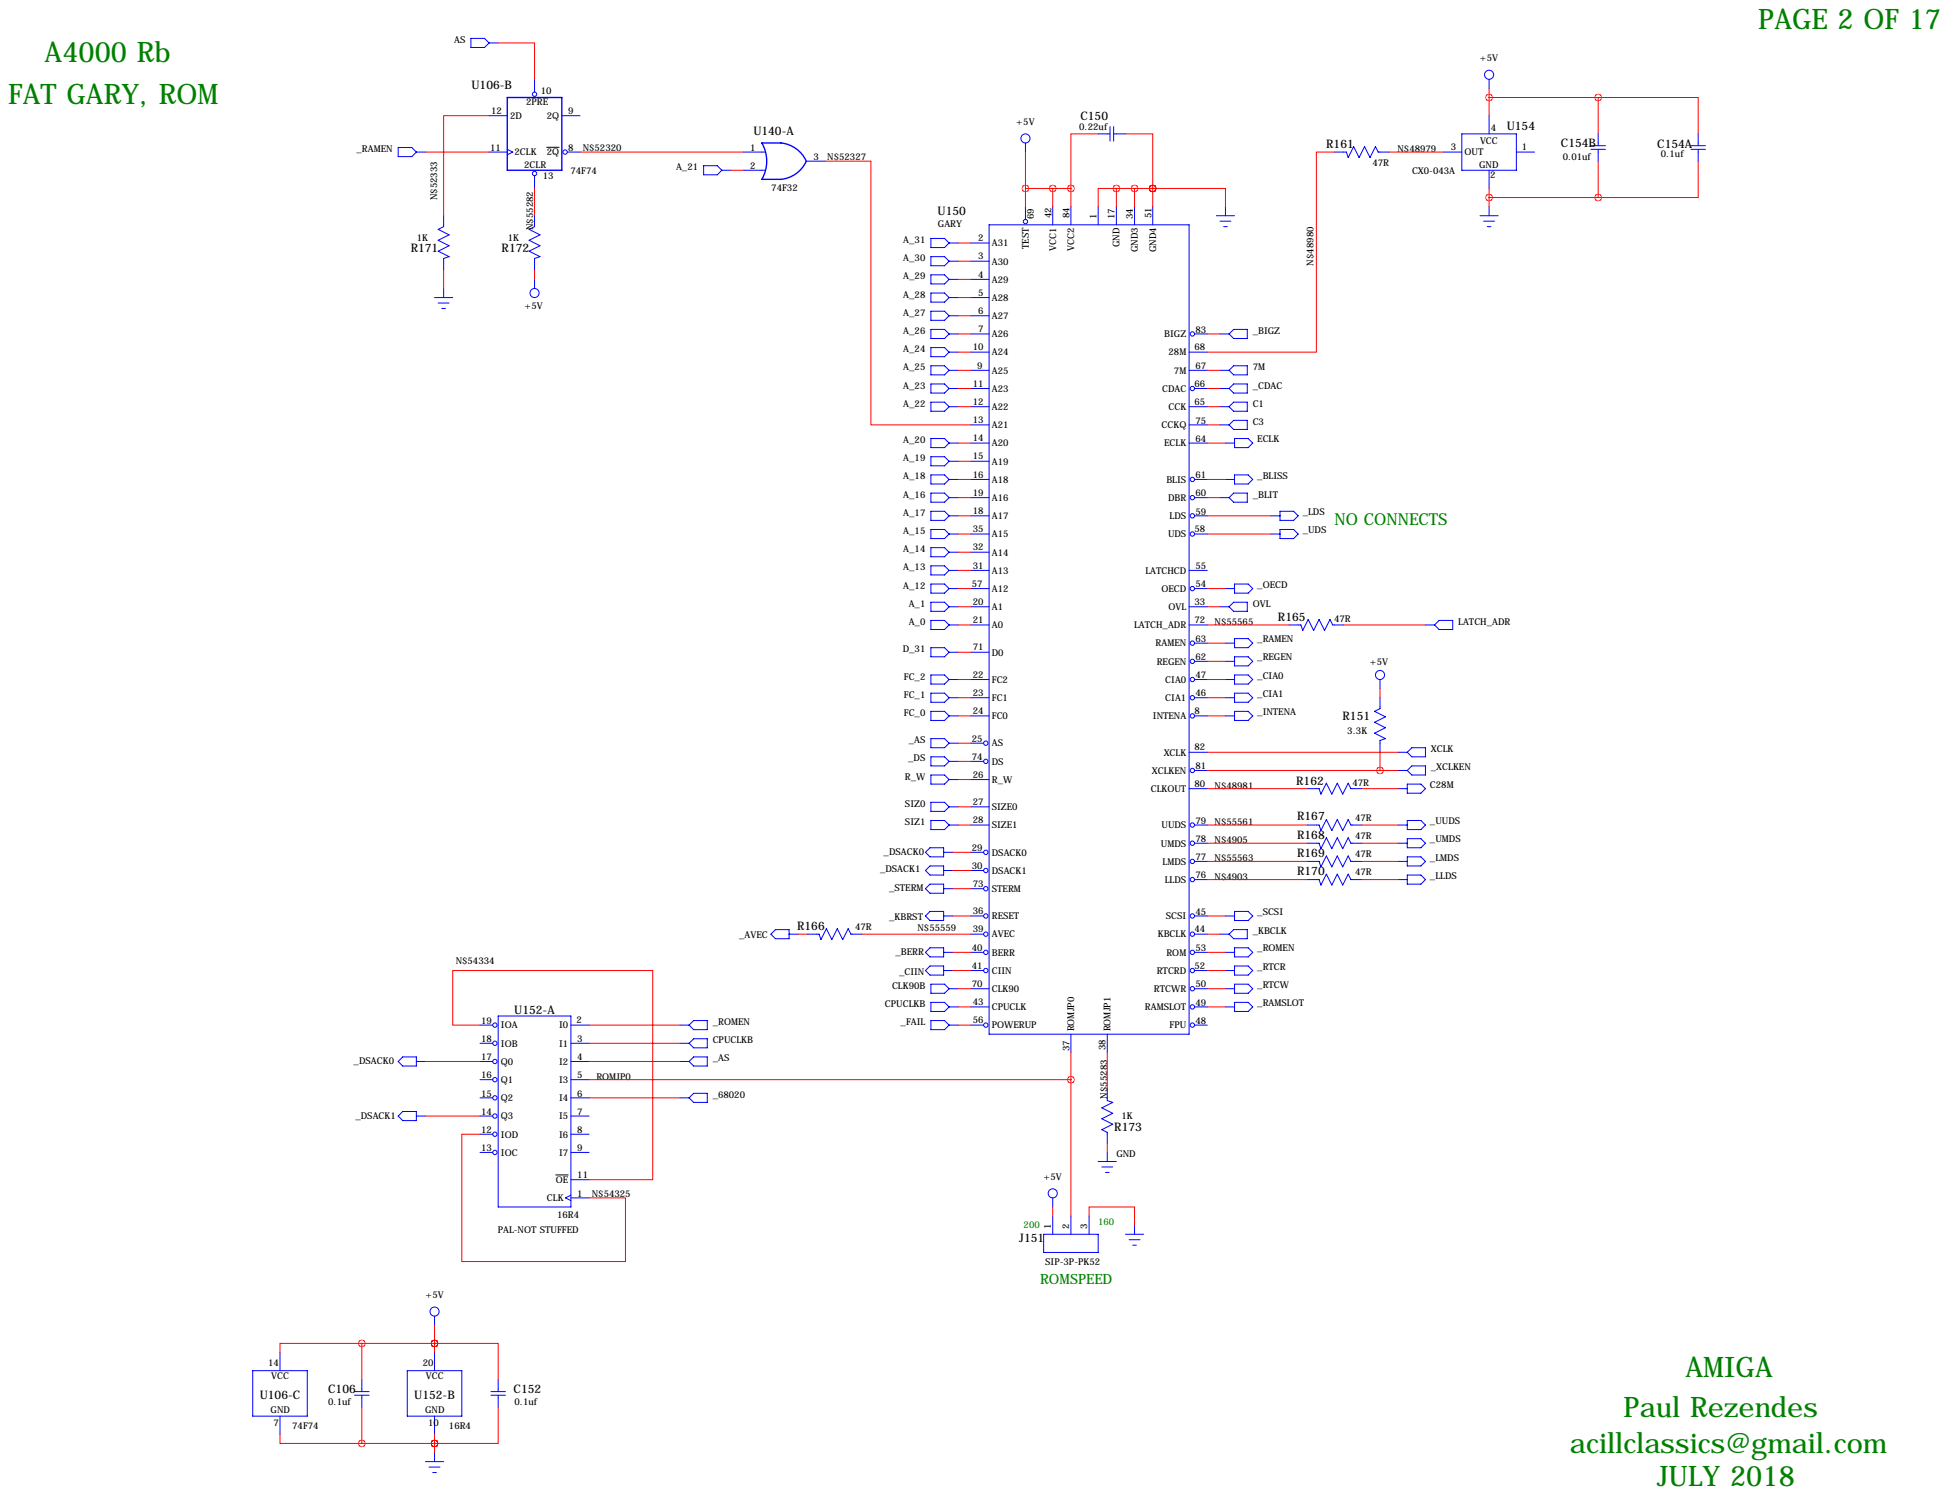
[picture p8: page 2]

# ROMs, RTC, keyboard, power in

R178

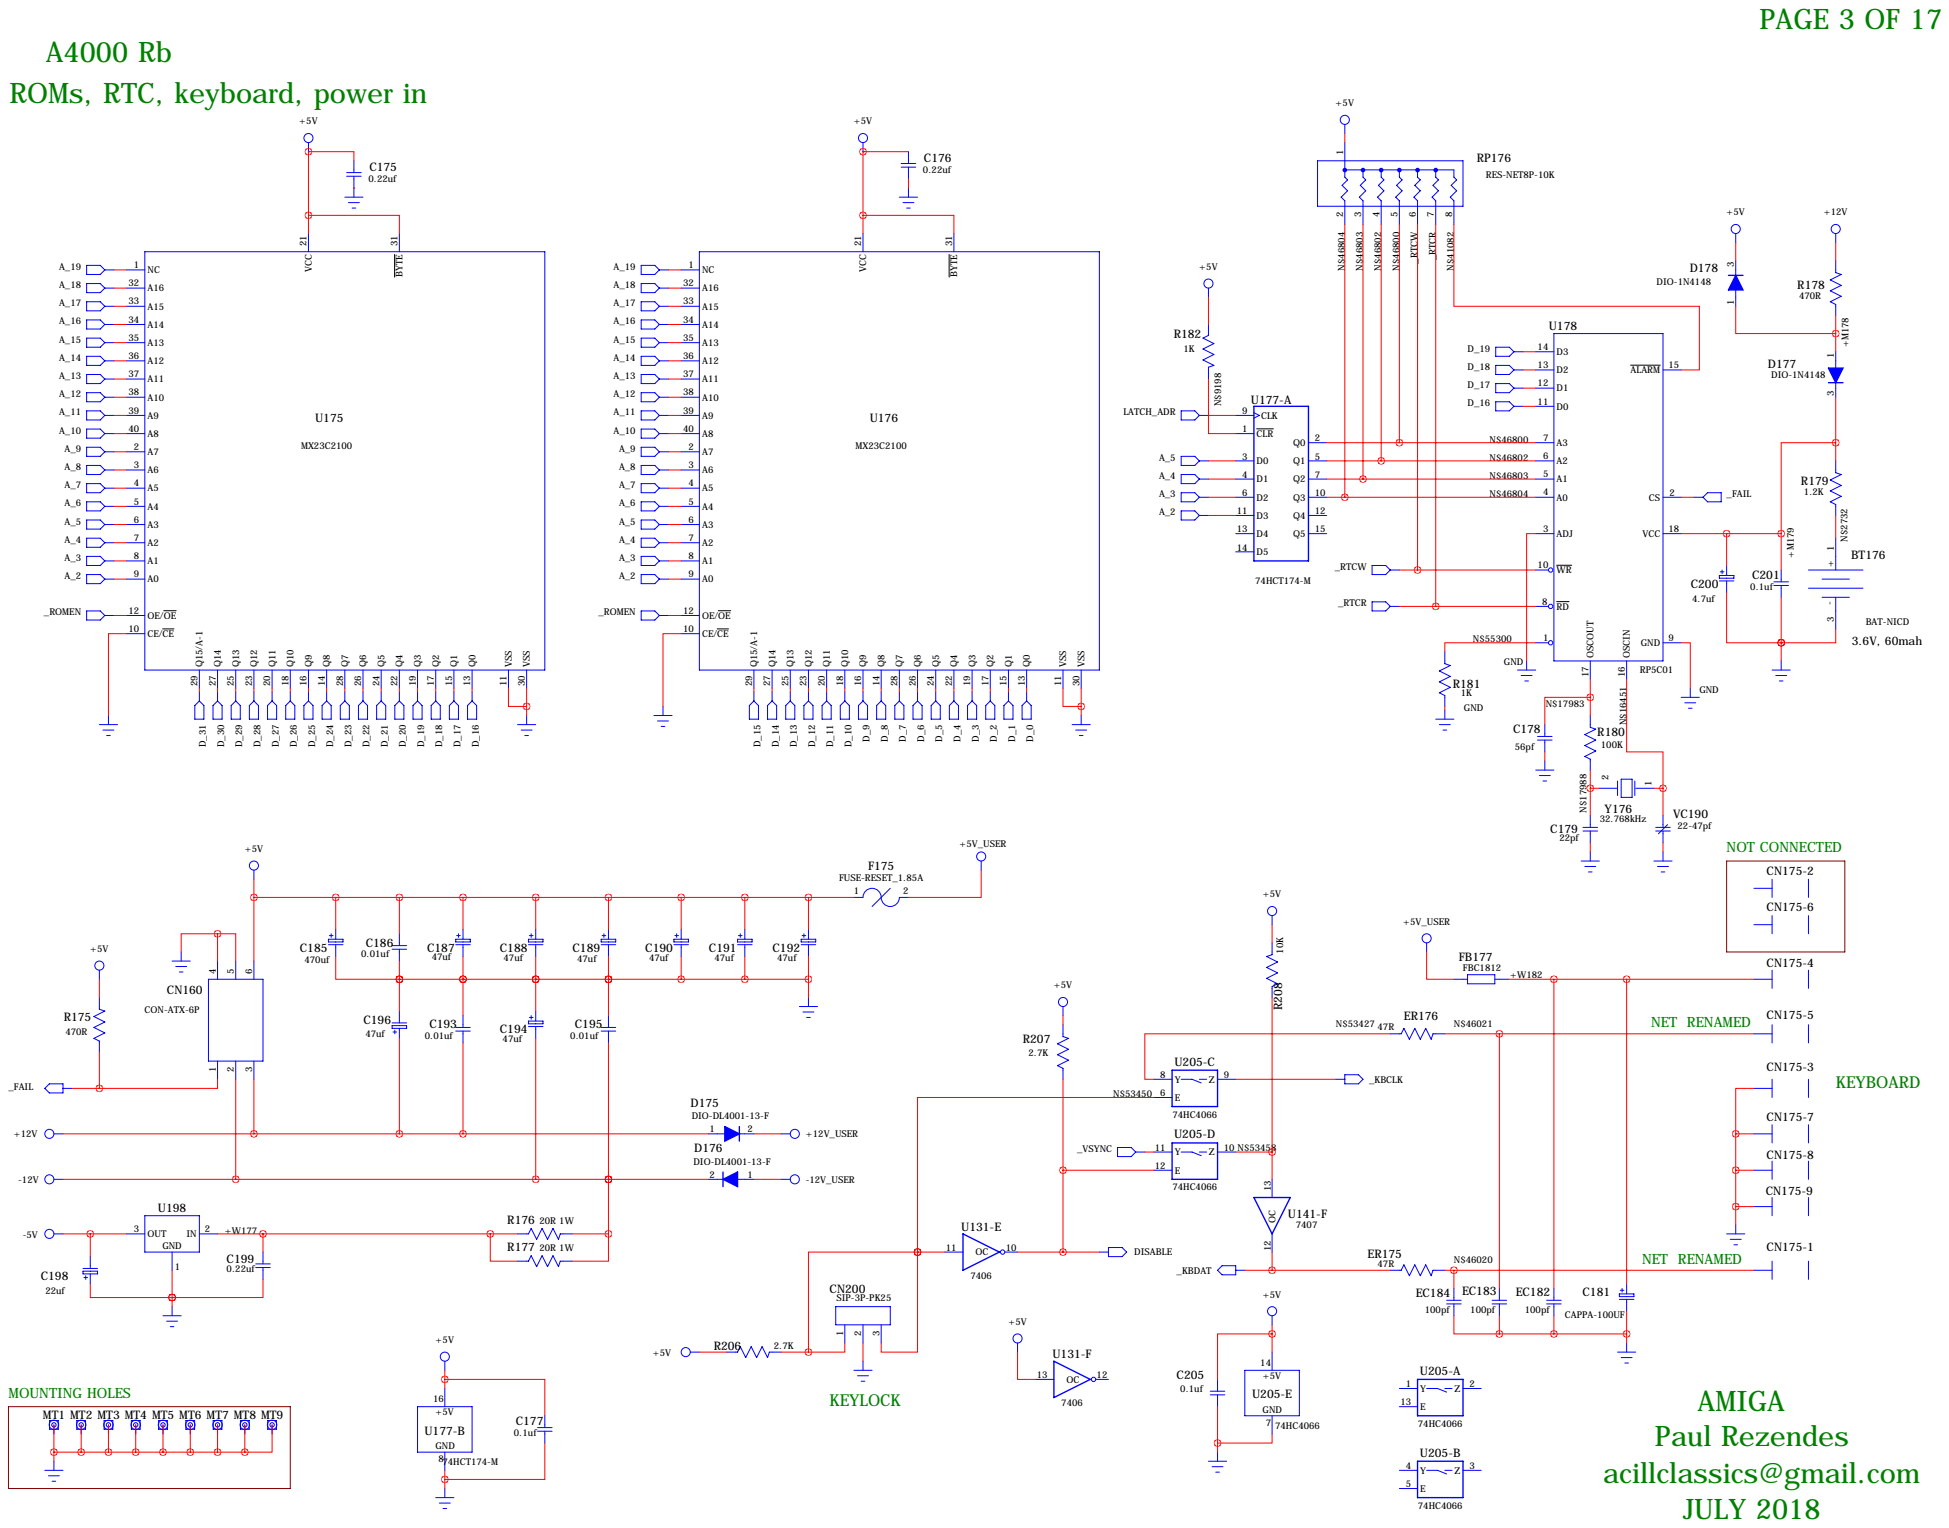
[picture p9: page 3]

# ALICE AND PALS

U212

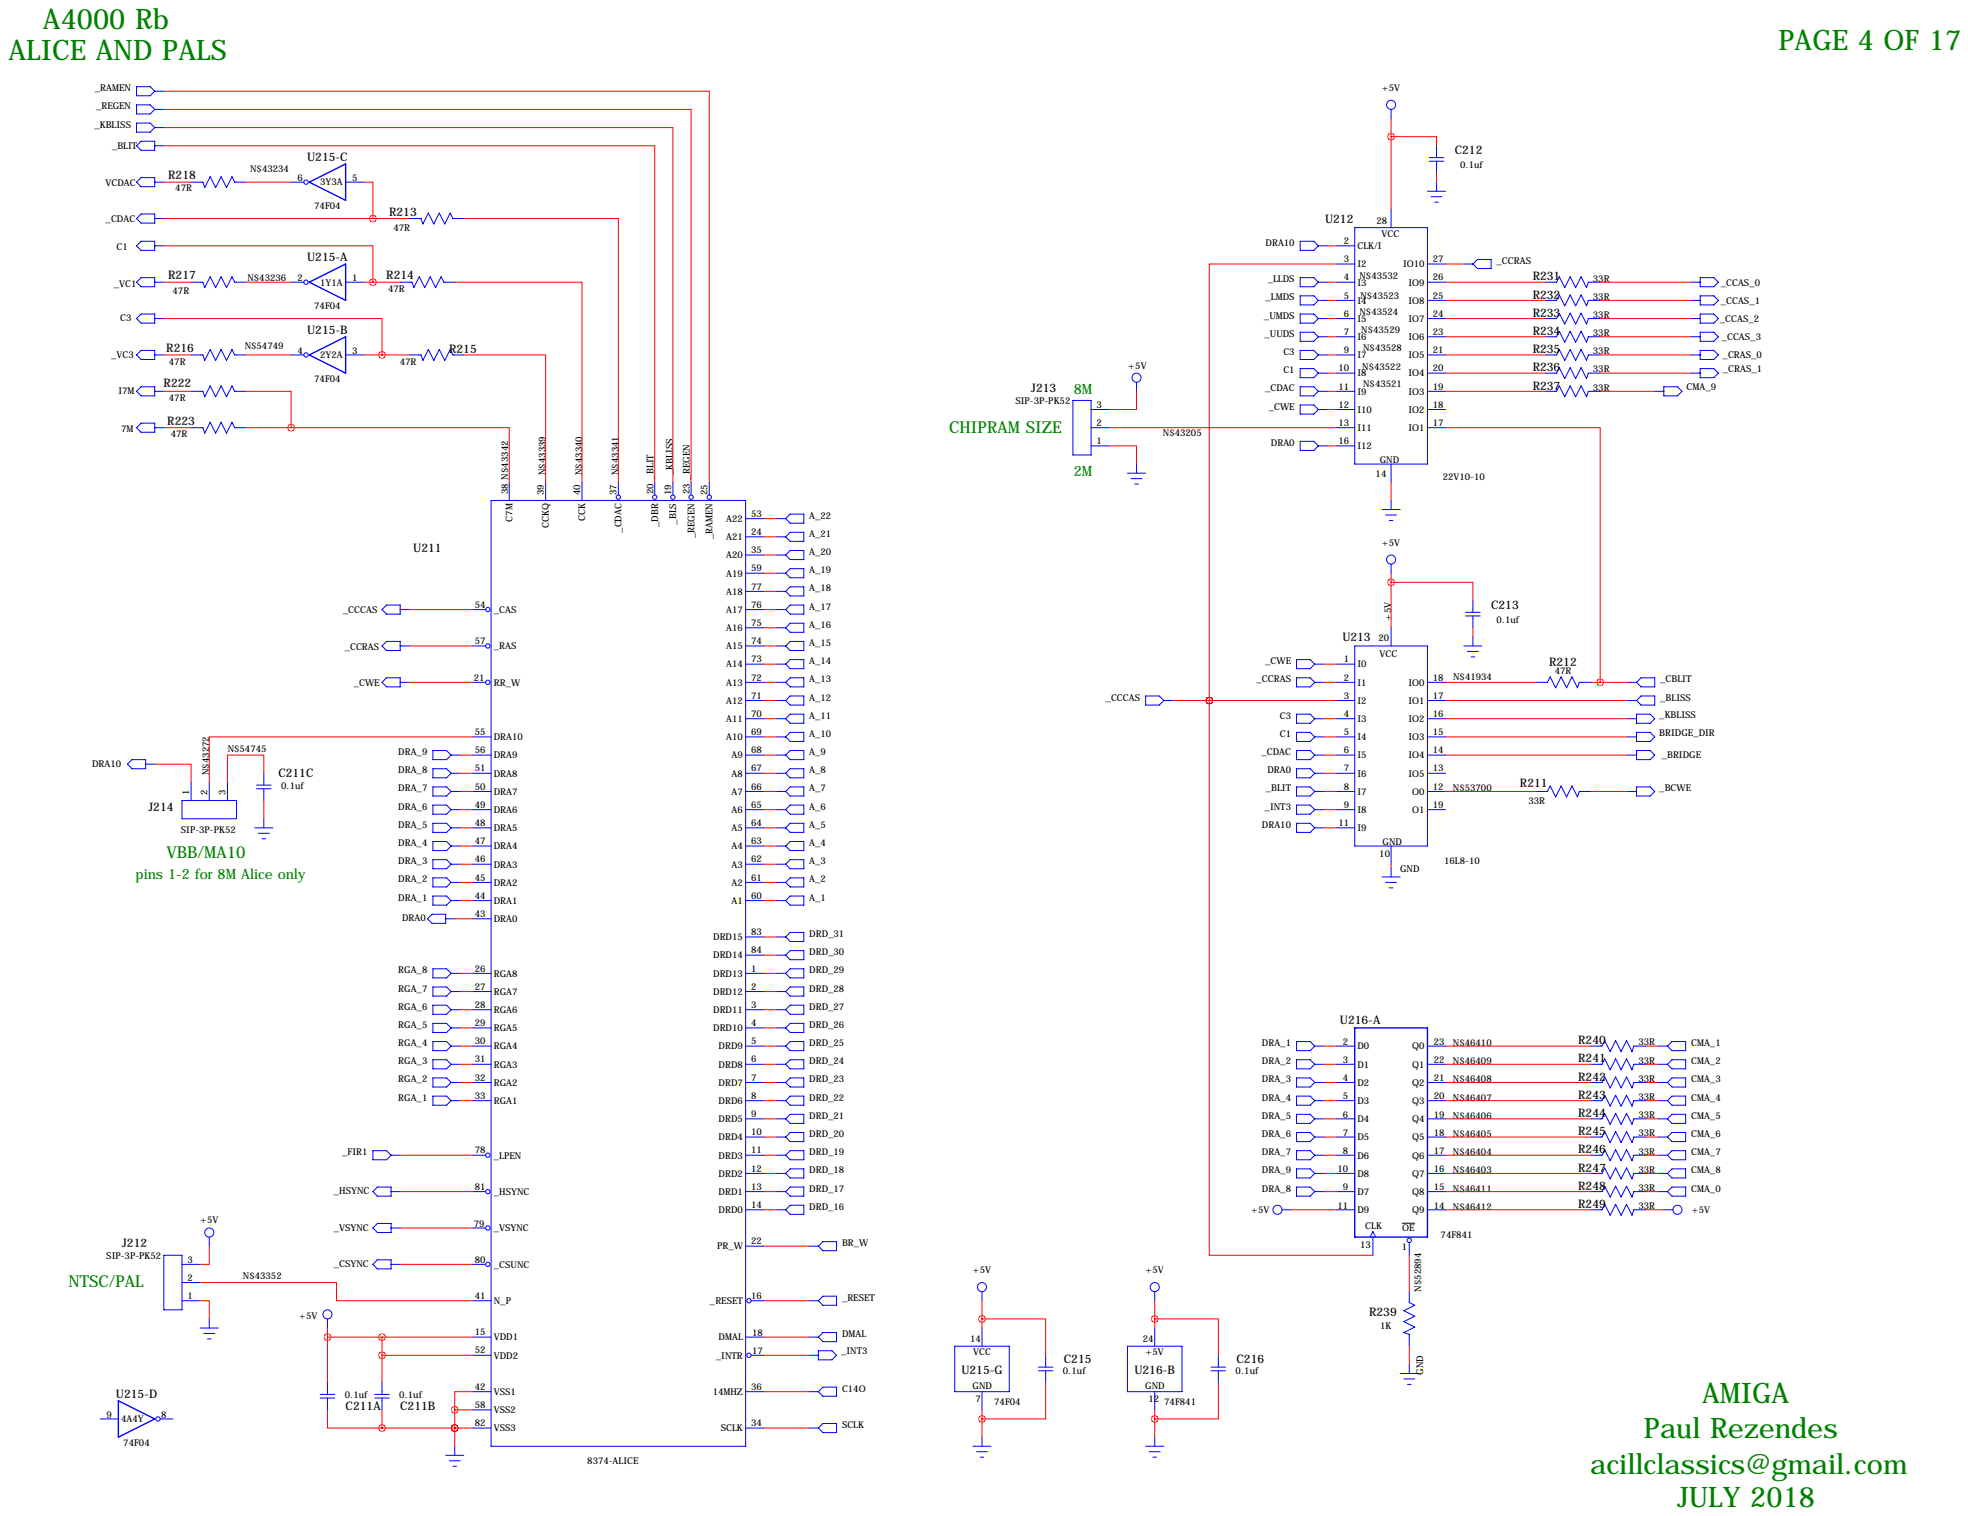
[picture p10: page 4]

SIP-3P-PK52
VBB/MA10
pins 1-2 for 8M Alice only

# BRIDGETTE AND ROM

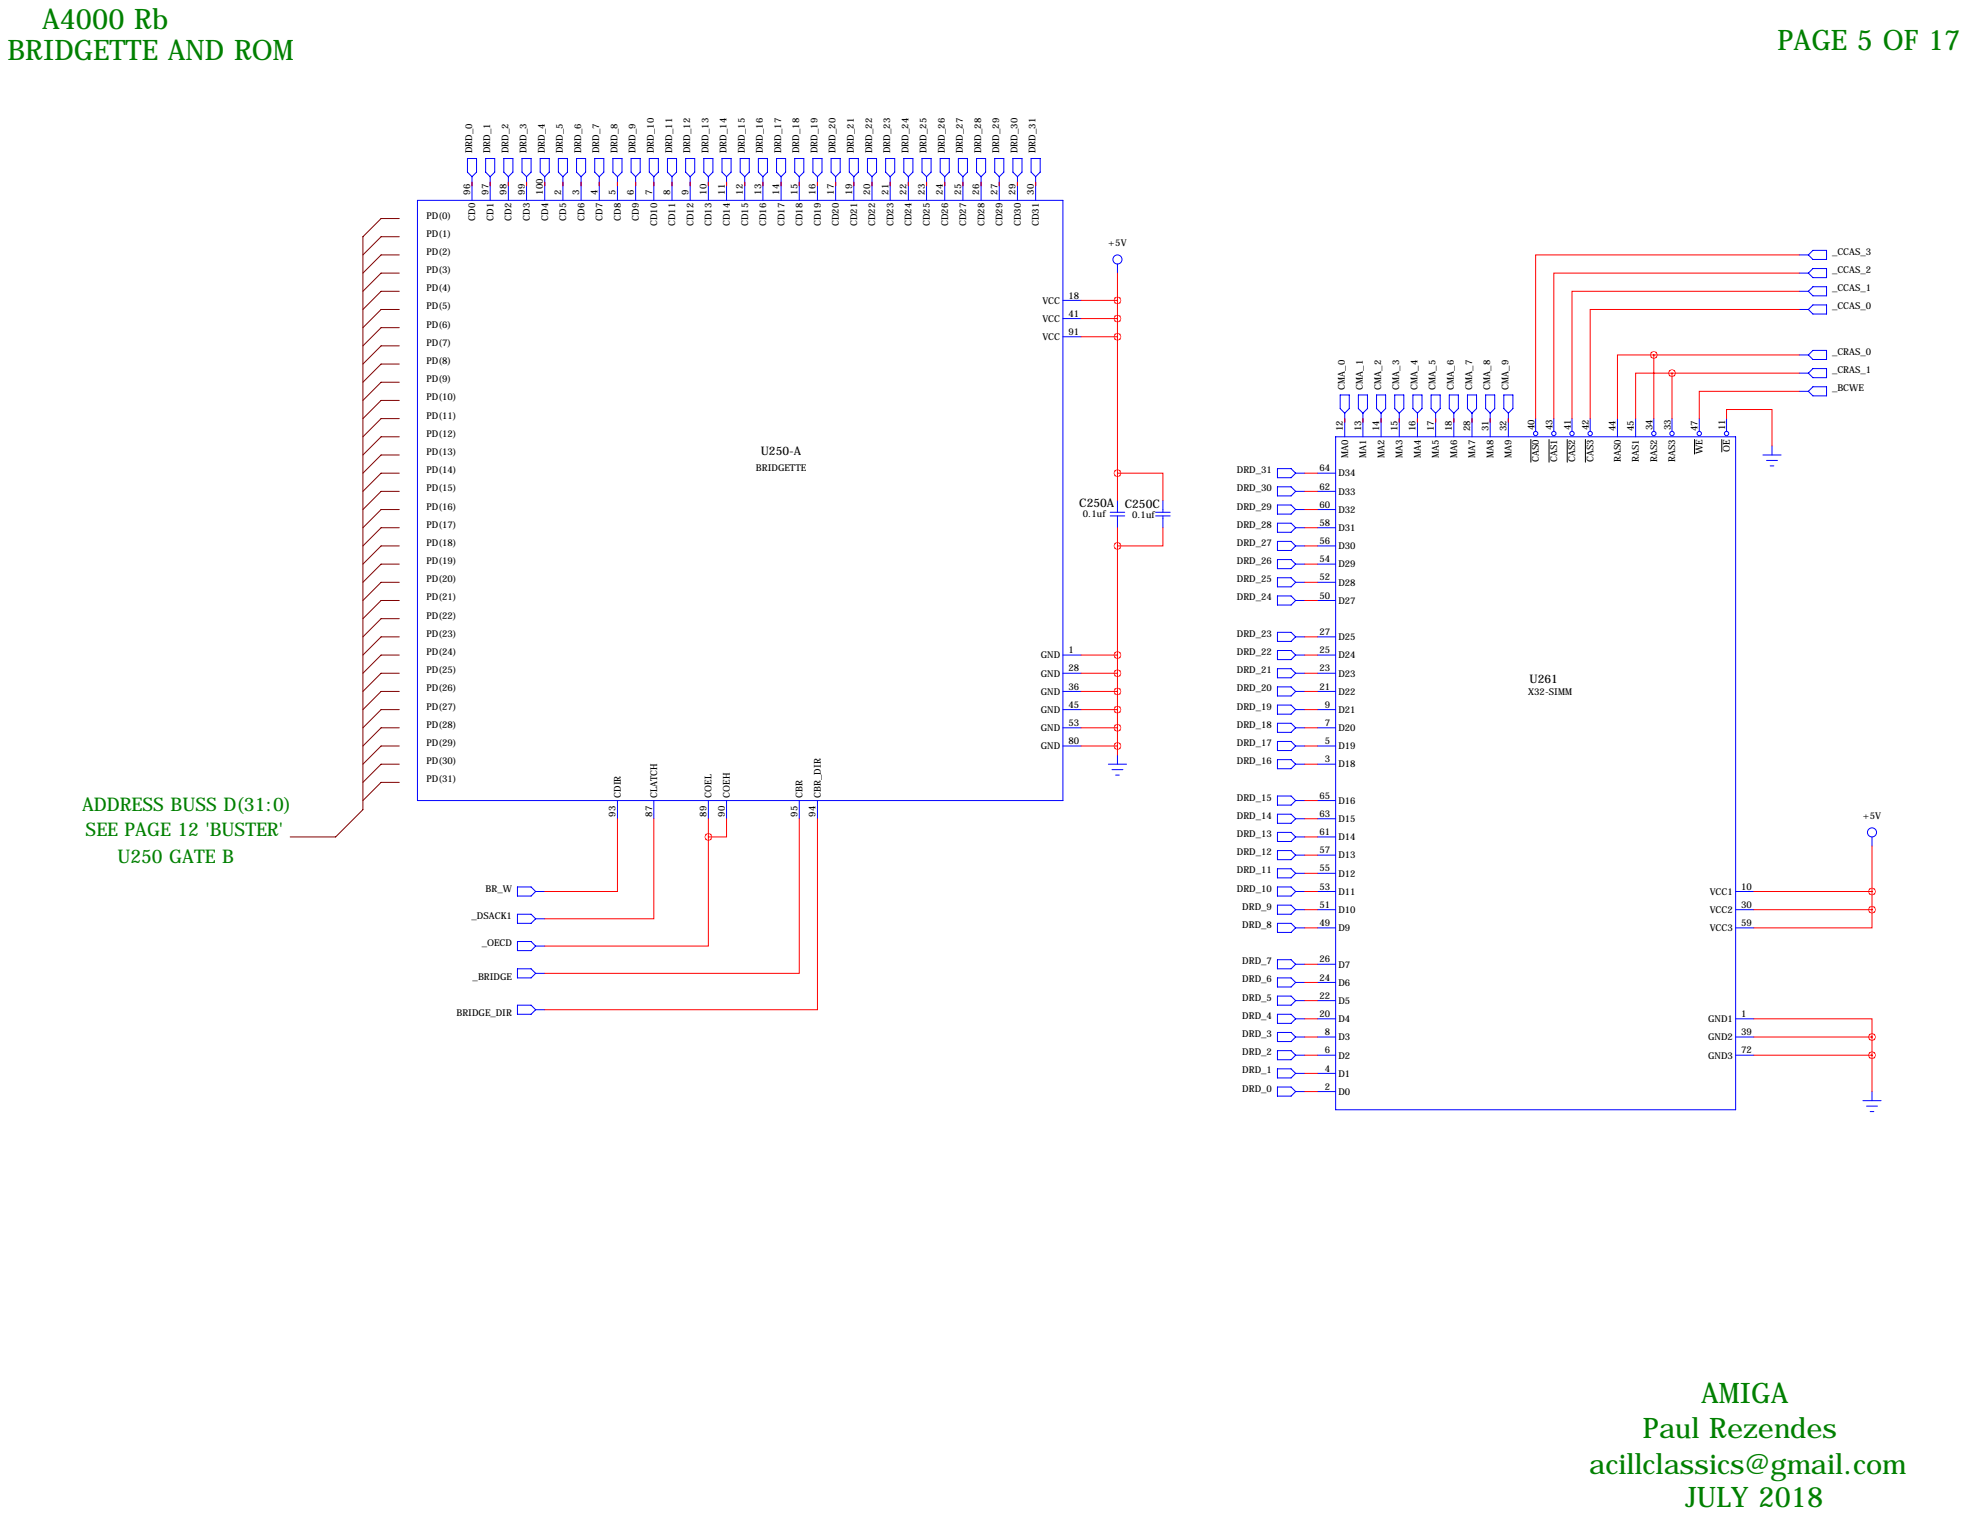
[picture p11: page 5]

# SERIAL

U300

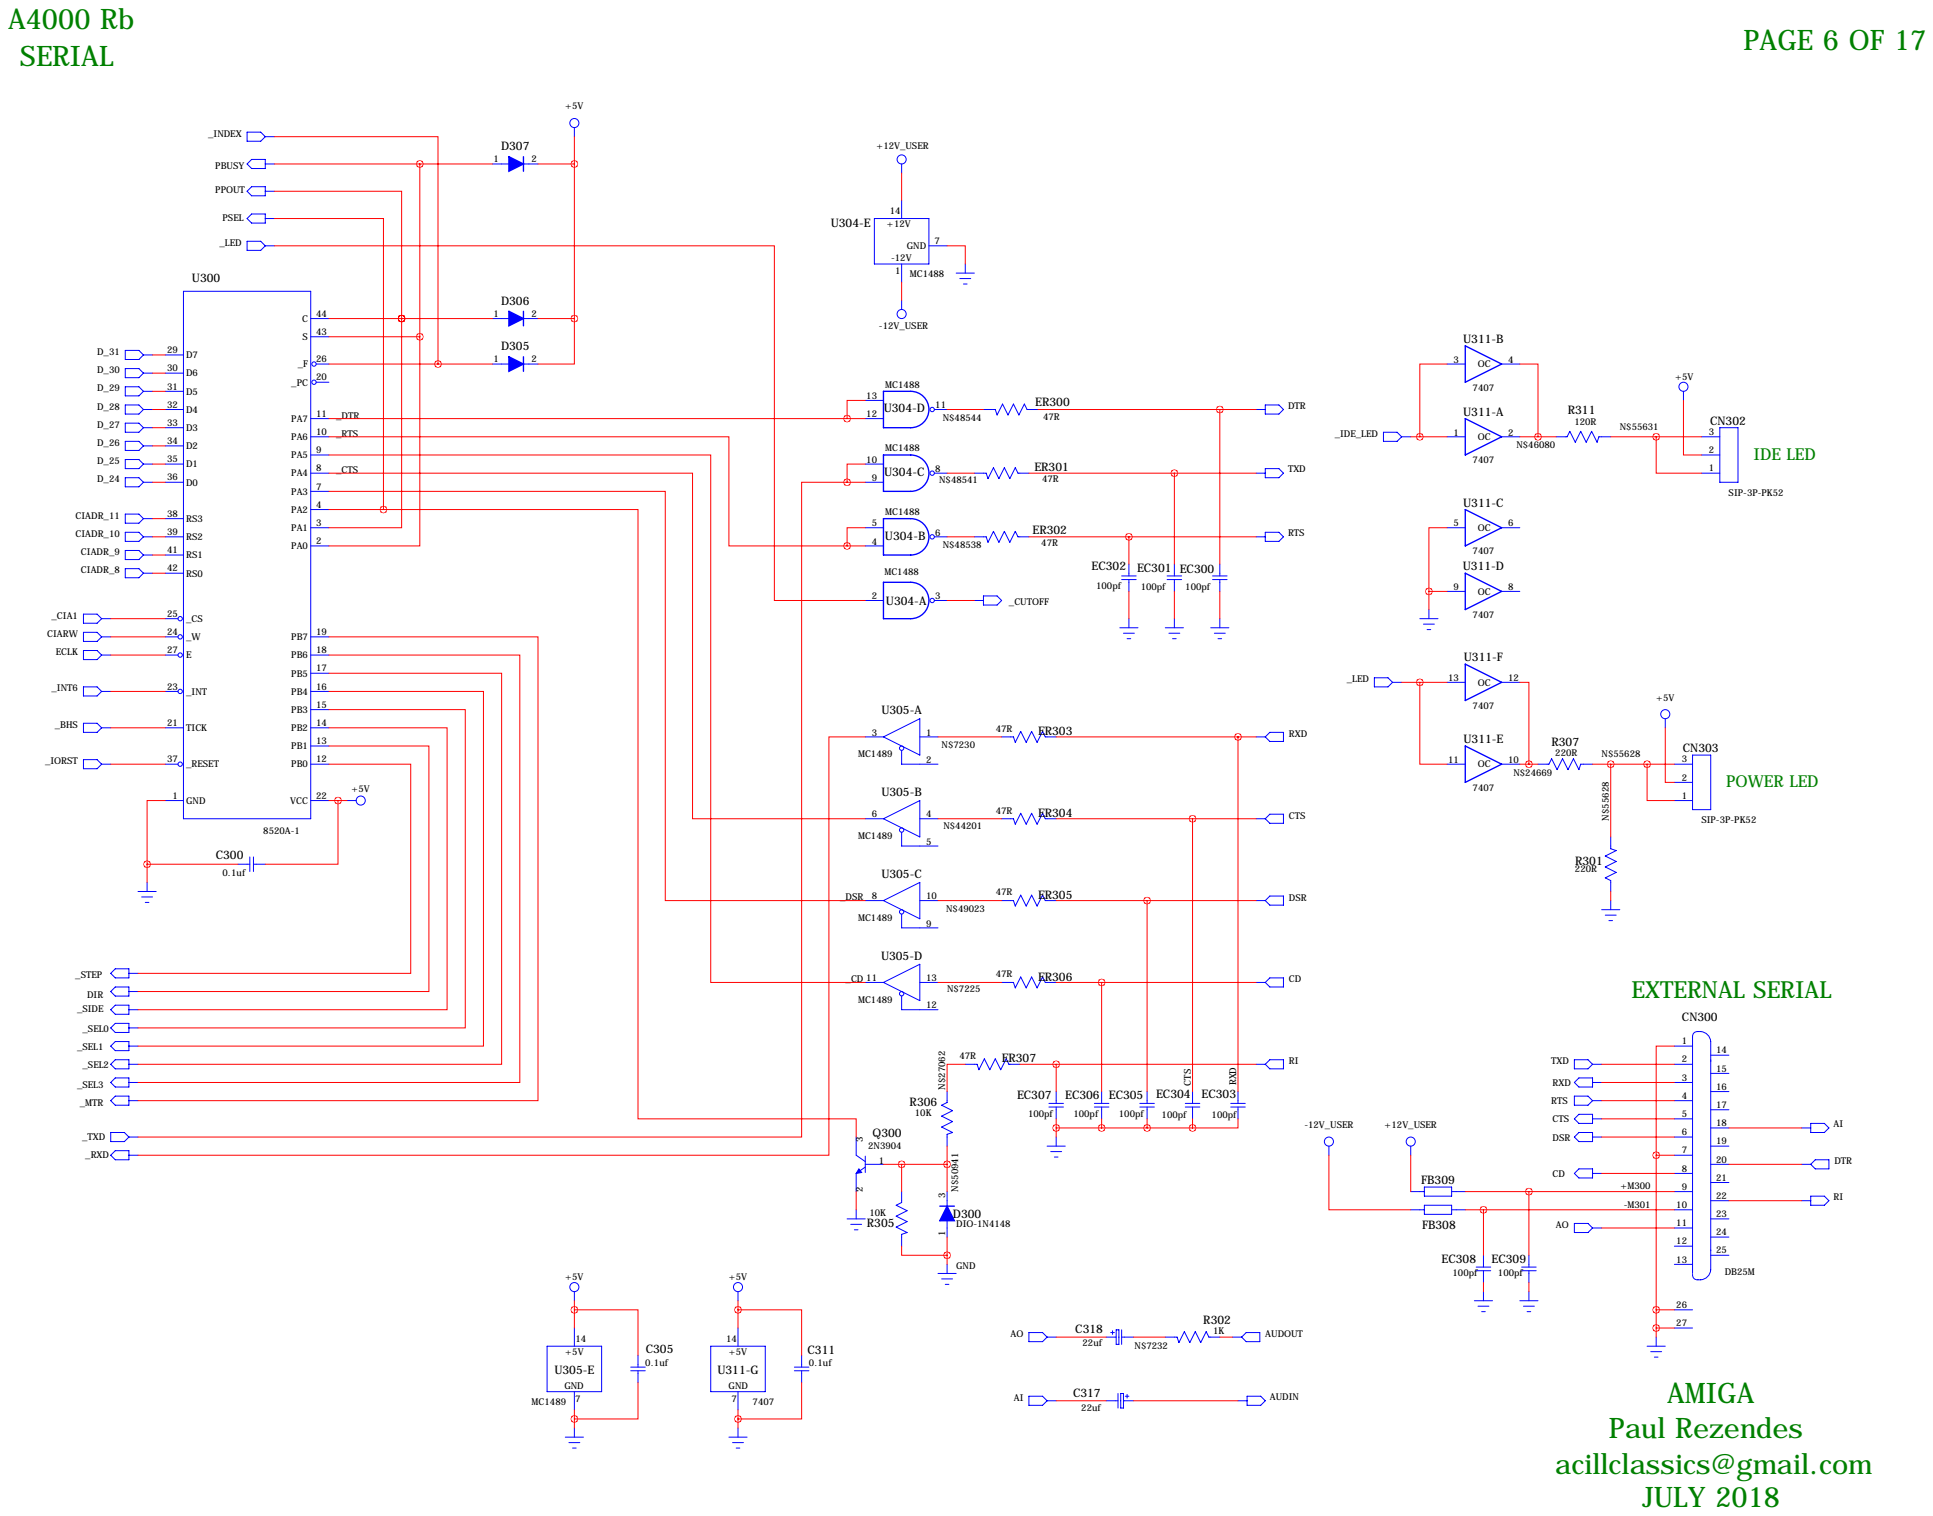
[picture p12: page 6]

26 _F 20 _PC 11 PA7 _DTR 10 PA6 _RTS

# PARALLEL

# INTERNAL FLOPPY

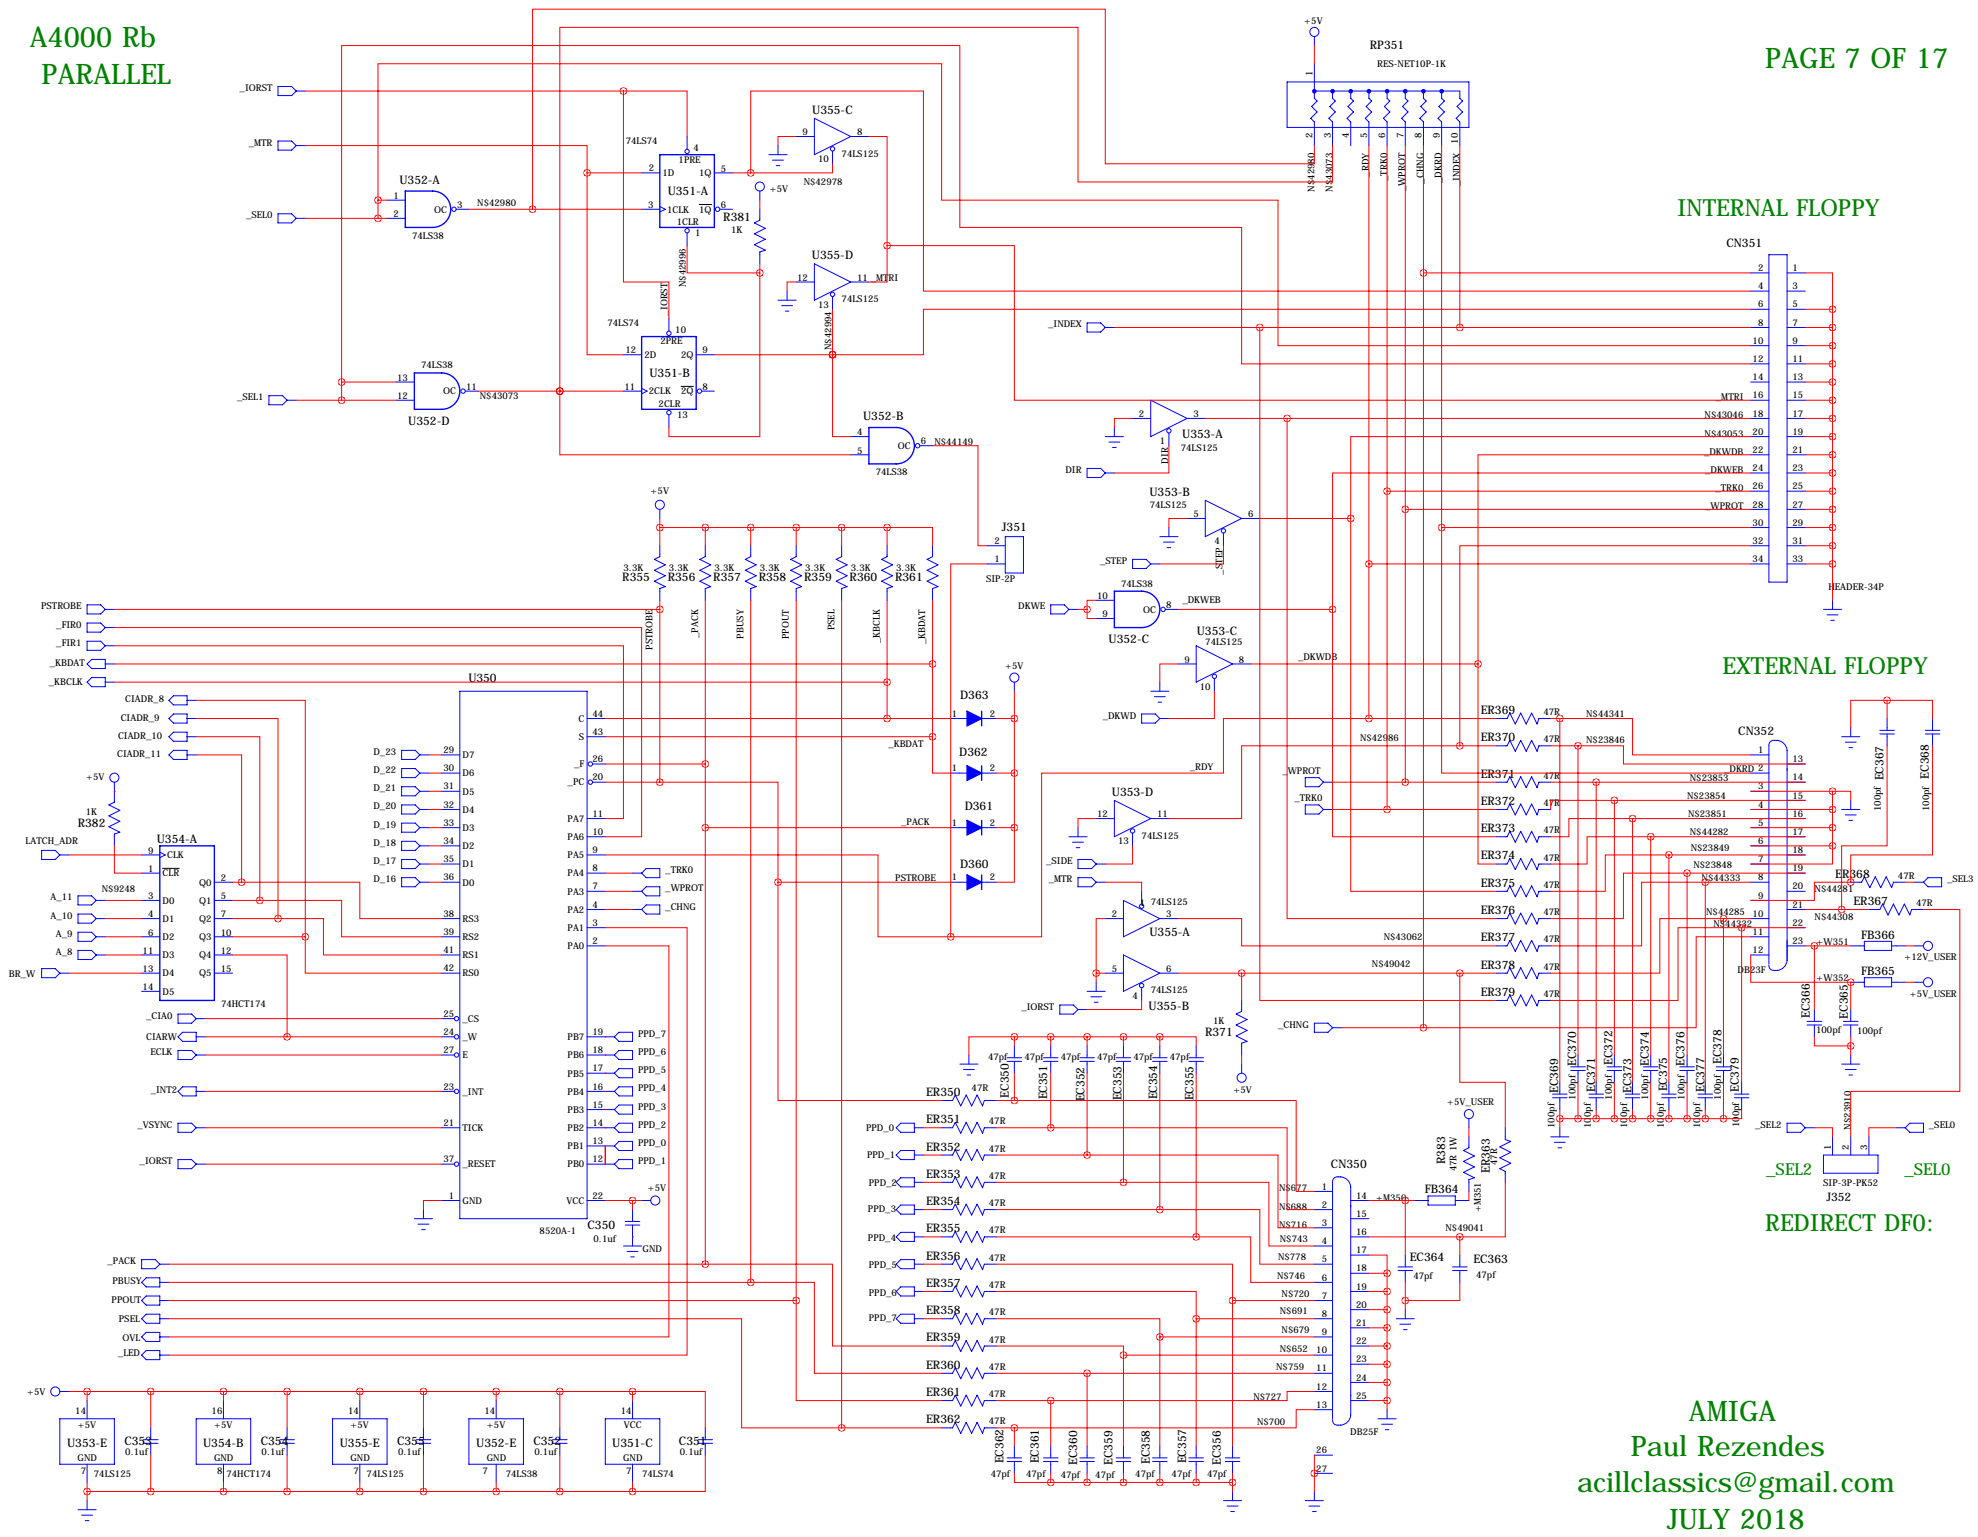
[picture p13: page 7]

# PAULA

C400B

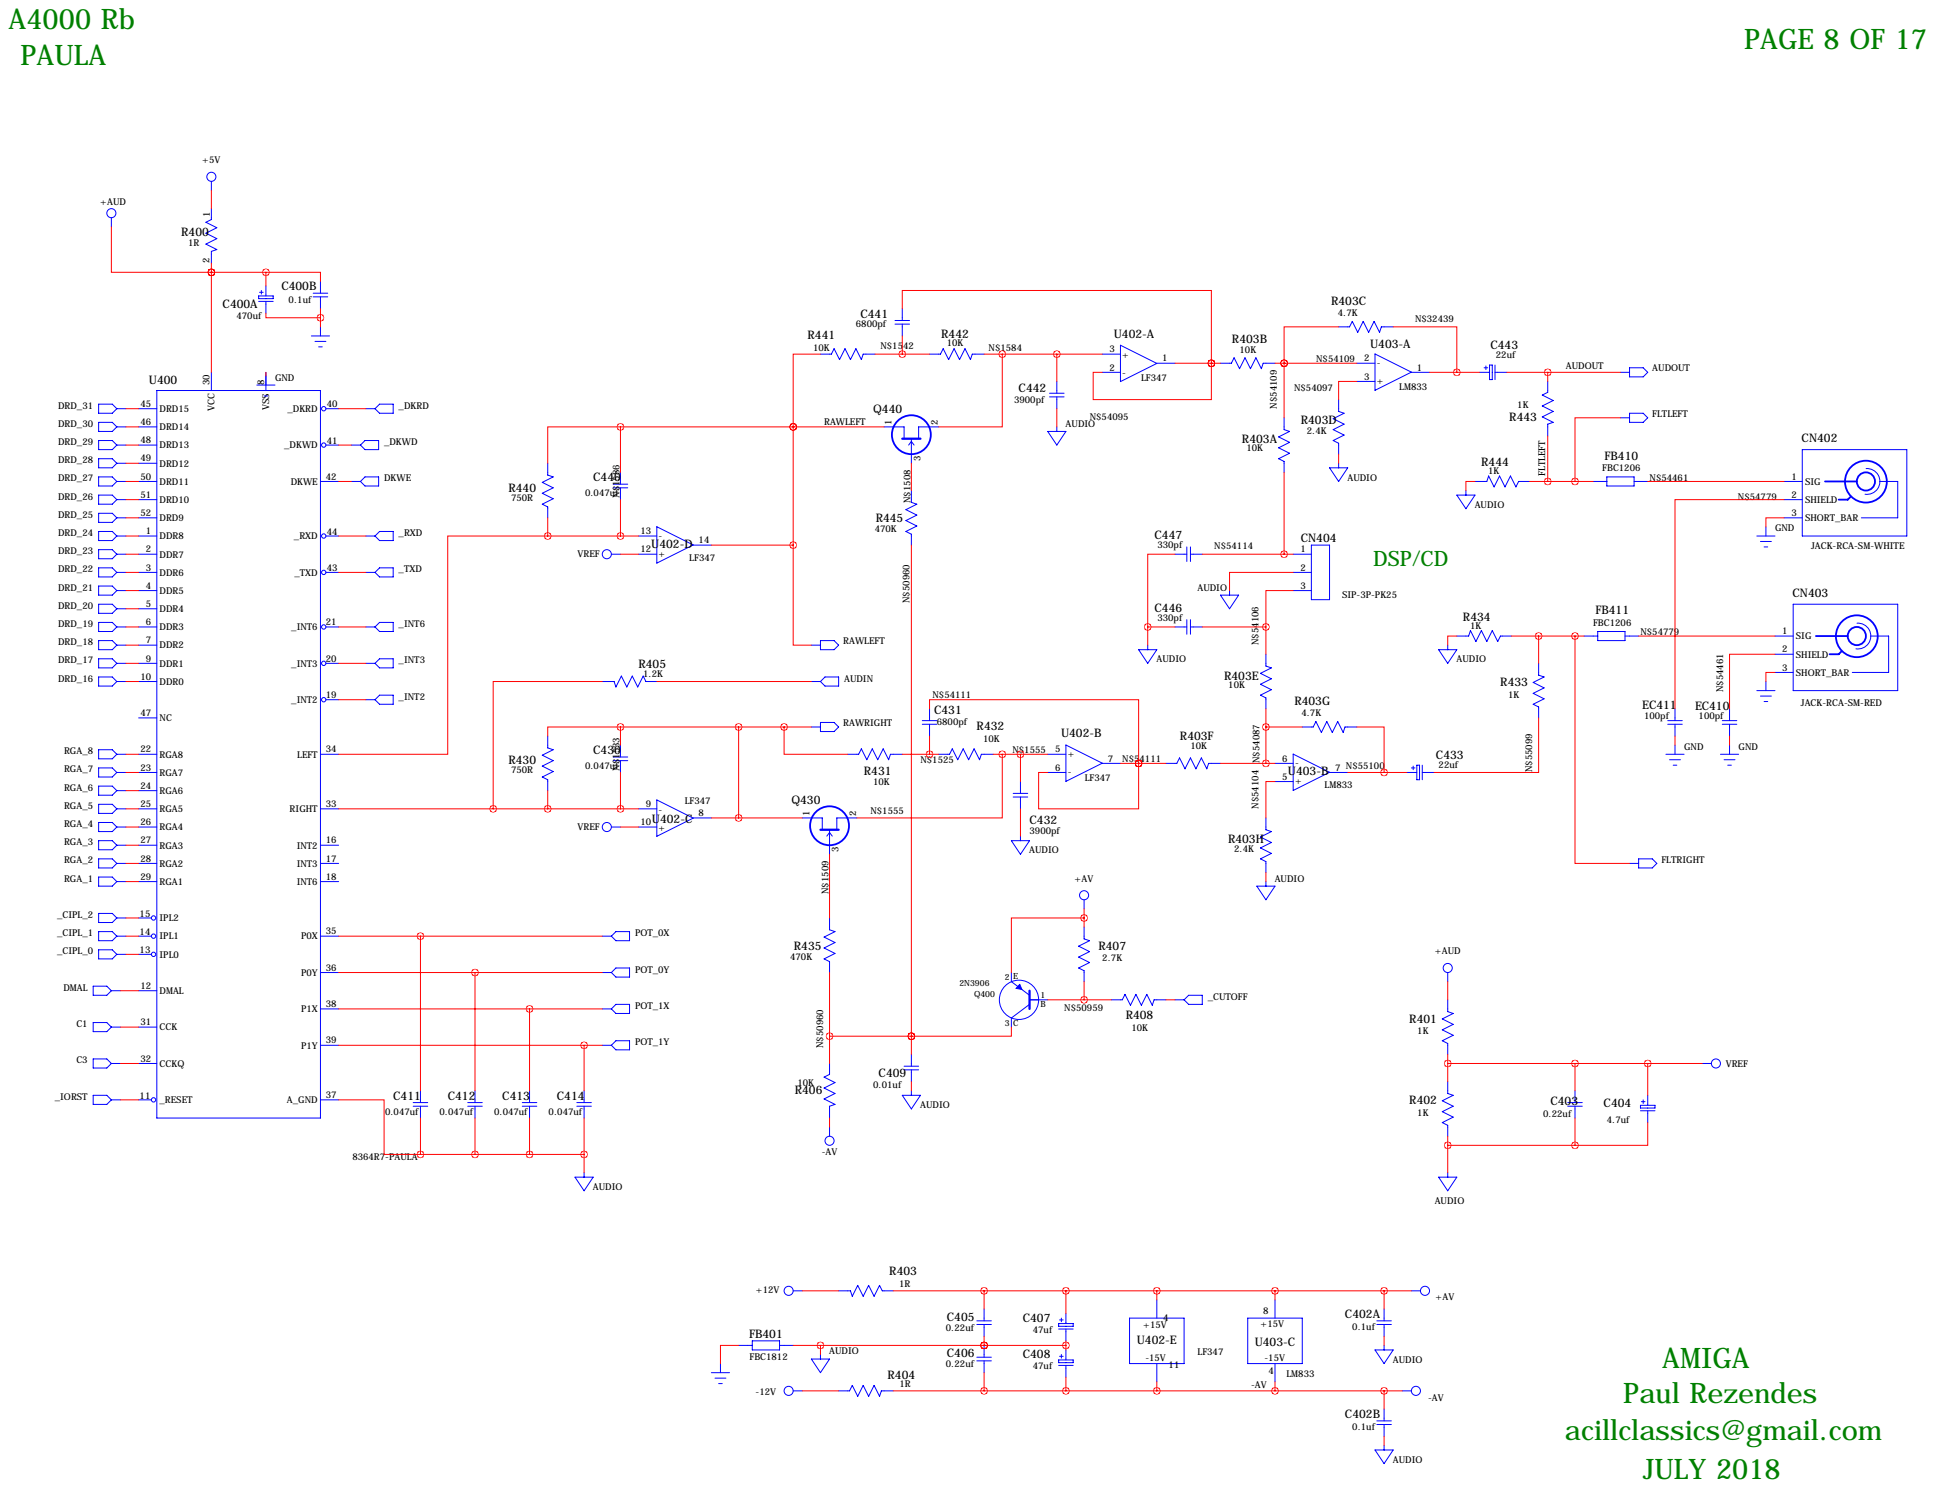
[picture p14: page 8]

JACK-RCA-SM-WHITE

JACK-RCA-SM-RED

# LISA PART A

# 68 OHM RESISTORS ON SCHEMATIC

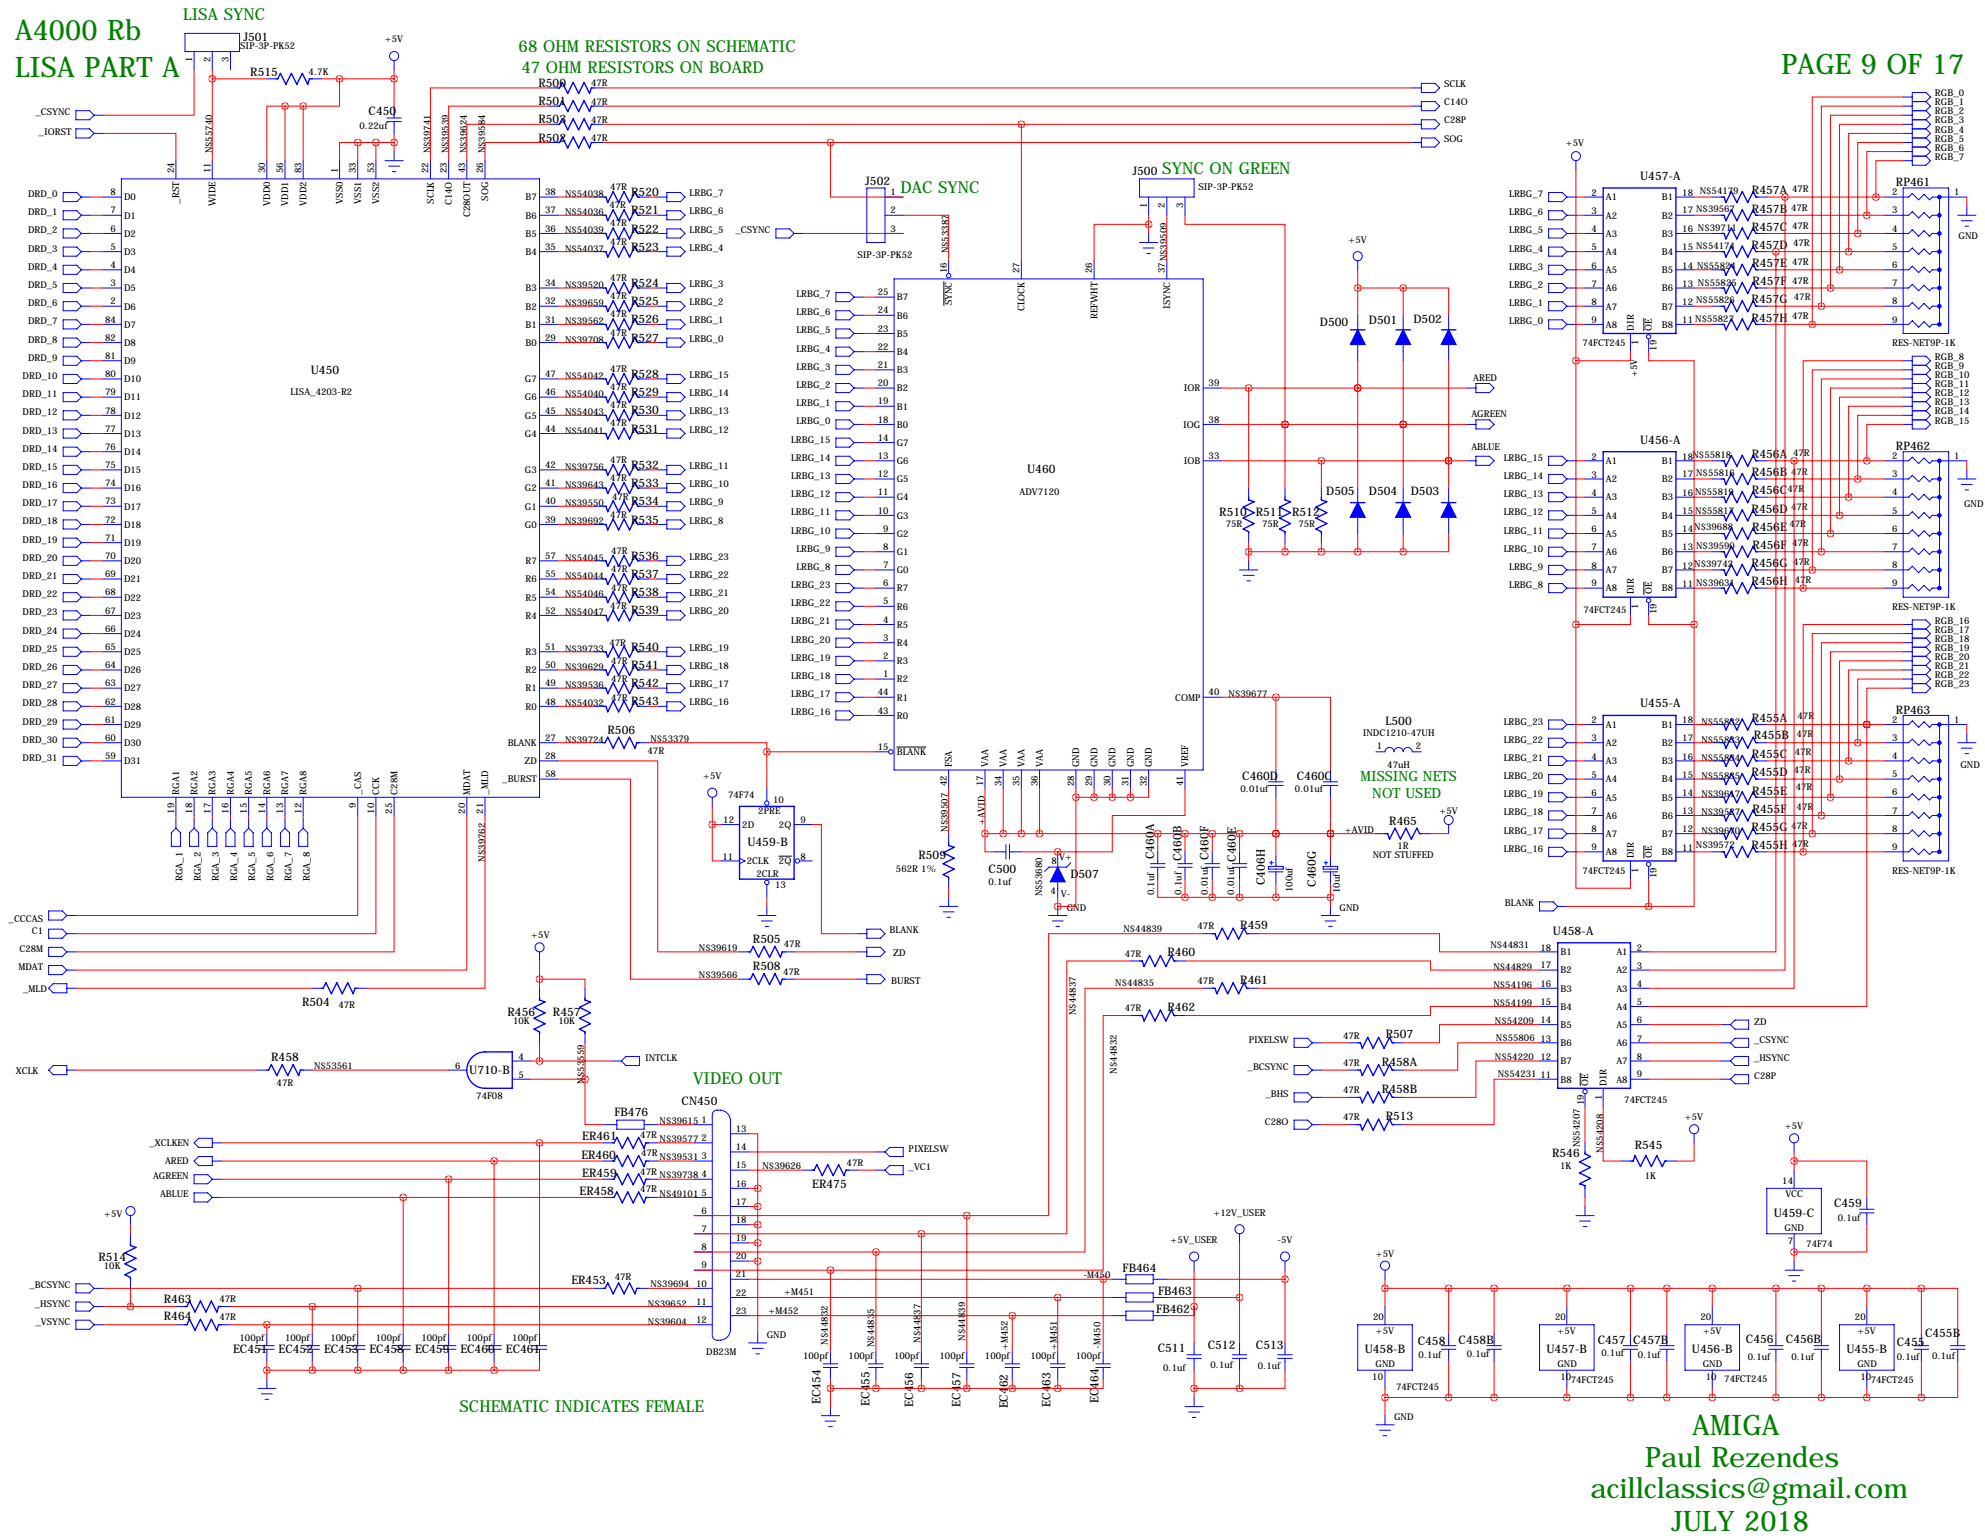
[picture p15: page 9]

47 OHM RESISTORS ON BOARD

# LISA PART B

U459-A

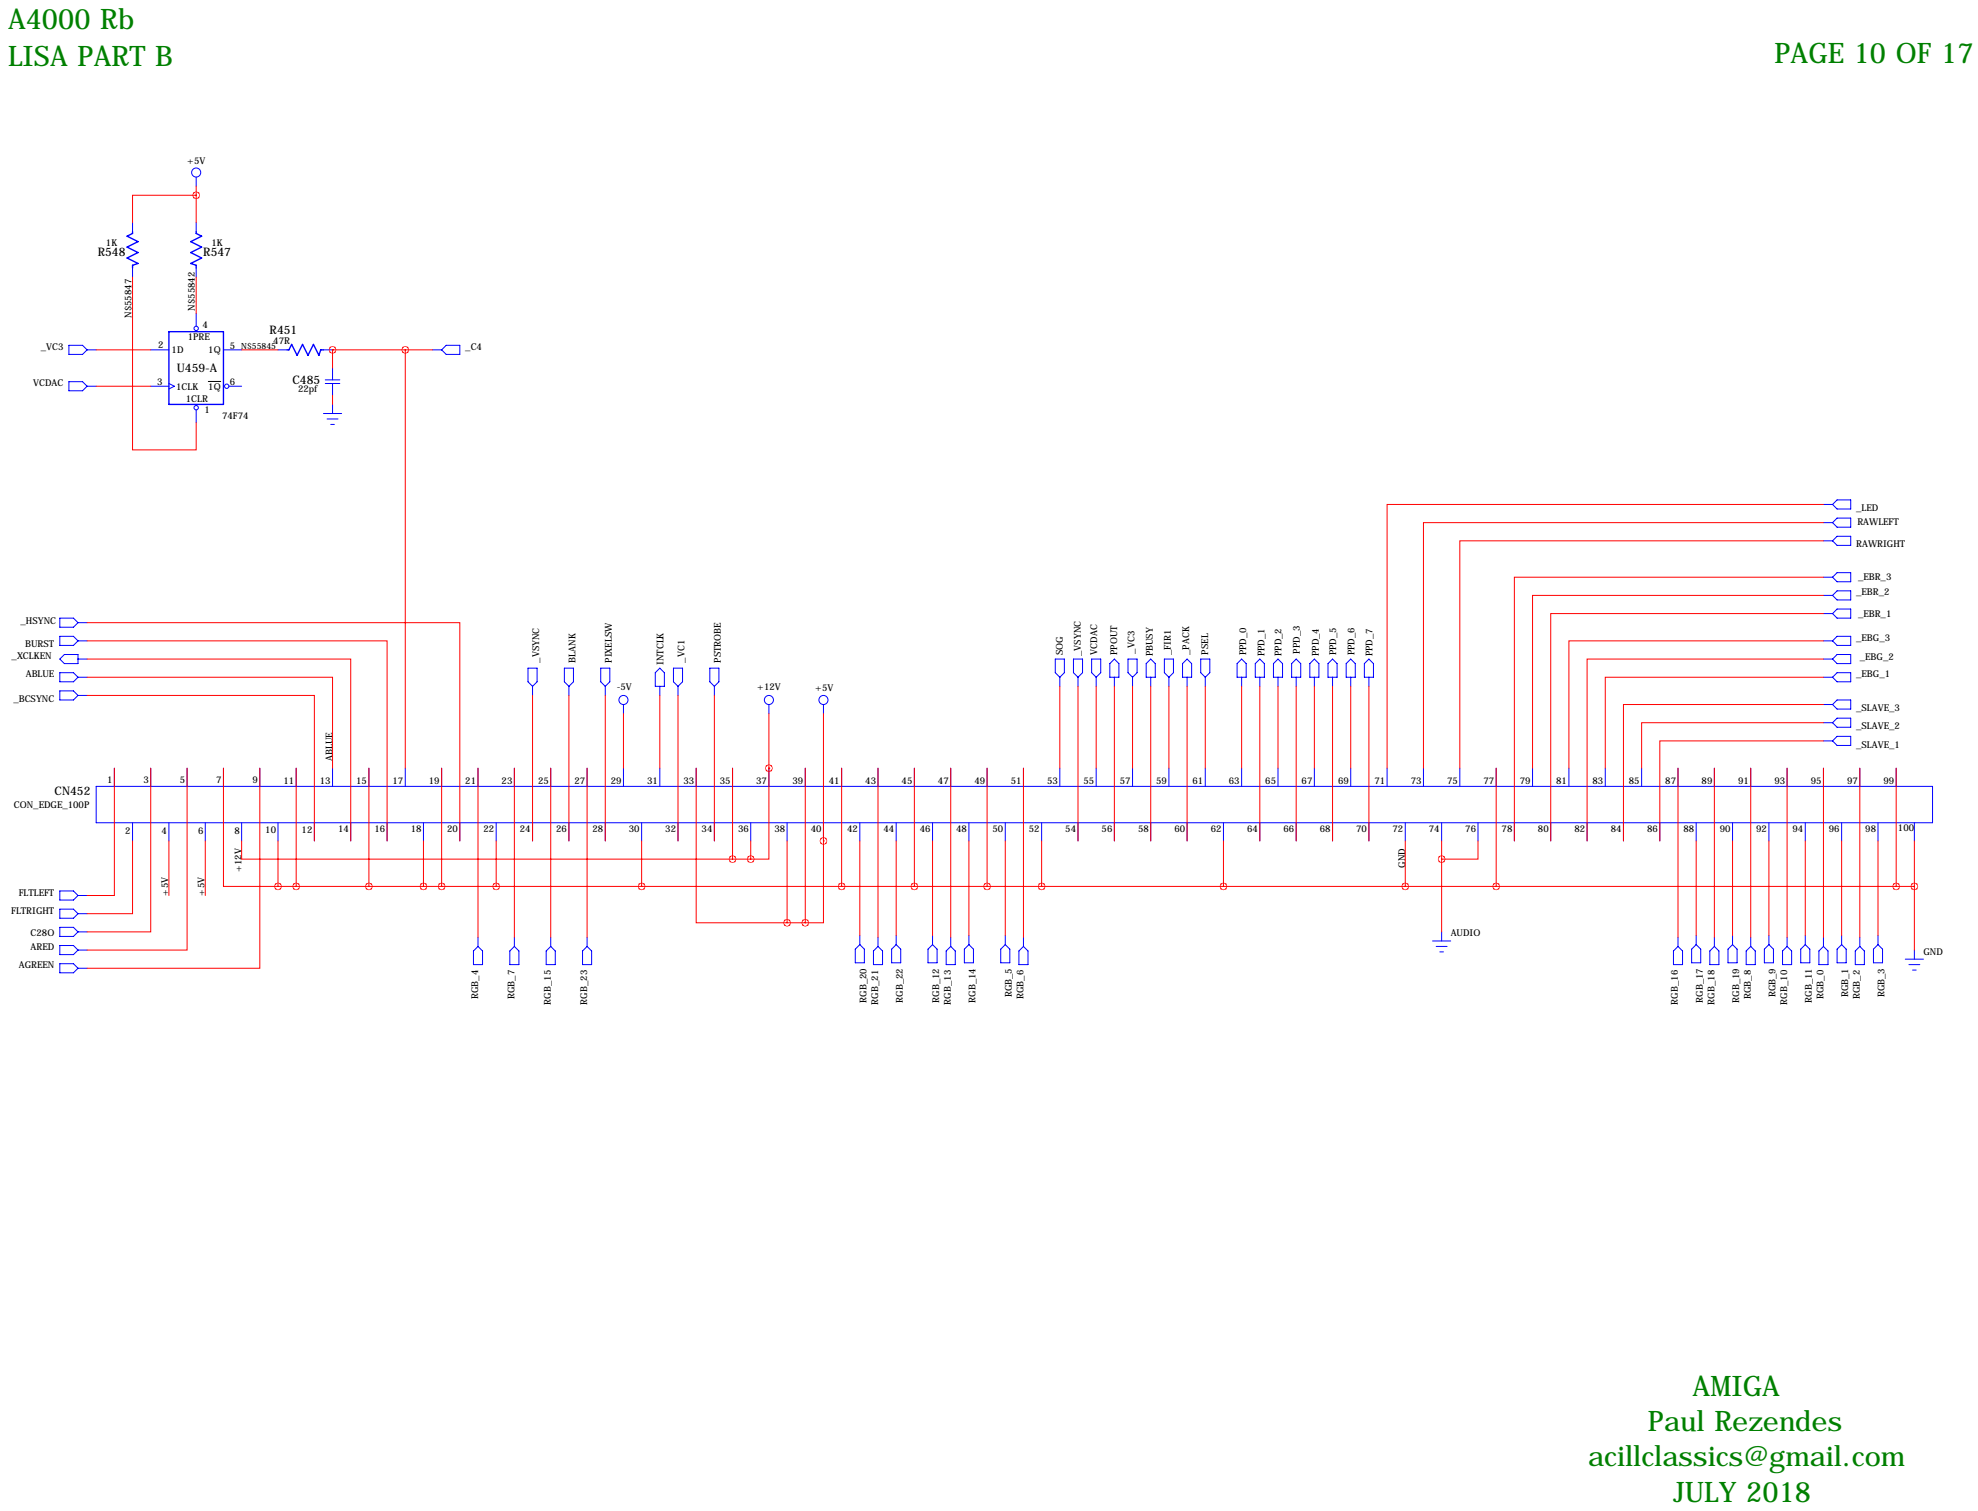
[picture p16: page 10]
AMIGA; 1CLR; 1CLK; 4 1PRE; CON_EDGE_100P; BLANK; BURST; GND; INTCLK; PBUSY; PIXELSW; PPOUT; PSEL; PPD_0; PPD_1; PPD_2; PPD_3; PPD_4; PPD_5; PPD_6; PPD_7; PSTROBE; RAWLEFT; RAWRIGHT; RGB_0; RGB_1; RGB_15; RGB_12; RGB_13; RGB_14; RGB_16; RGB_17; RGB_18; RGB_19; RGB_10; RGB_11; RGB_2; RGB_23; RGB_20; RGB_21; RGB_22; RGB_4; RGB_7; RGB_5; RGB_6; RGB_8; RGB_9; RGB_3; SOG; VCDAC; _EBG_1; _EBG_2; _EBG_3; _EBR_1; _EBR_2; _EBR_3; _FIR1; _HSYNC; _LED; _PACK; _SLAVE_1; _SLAVE_2; _SLAVE_3; _VSYNC; _XCLKEN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

# EXPANSION_BUS_CONNECTOR

R635 1K

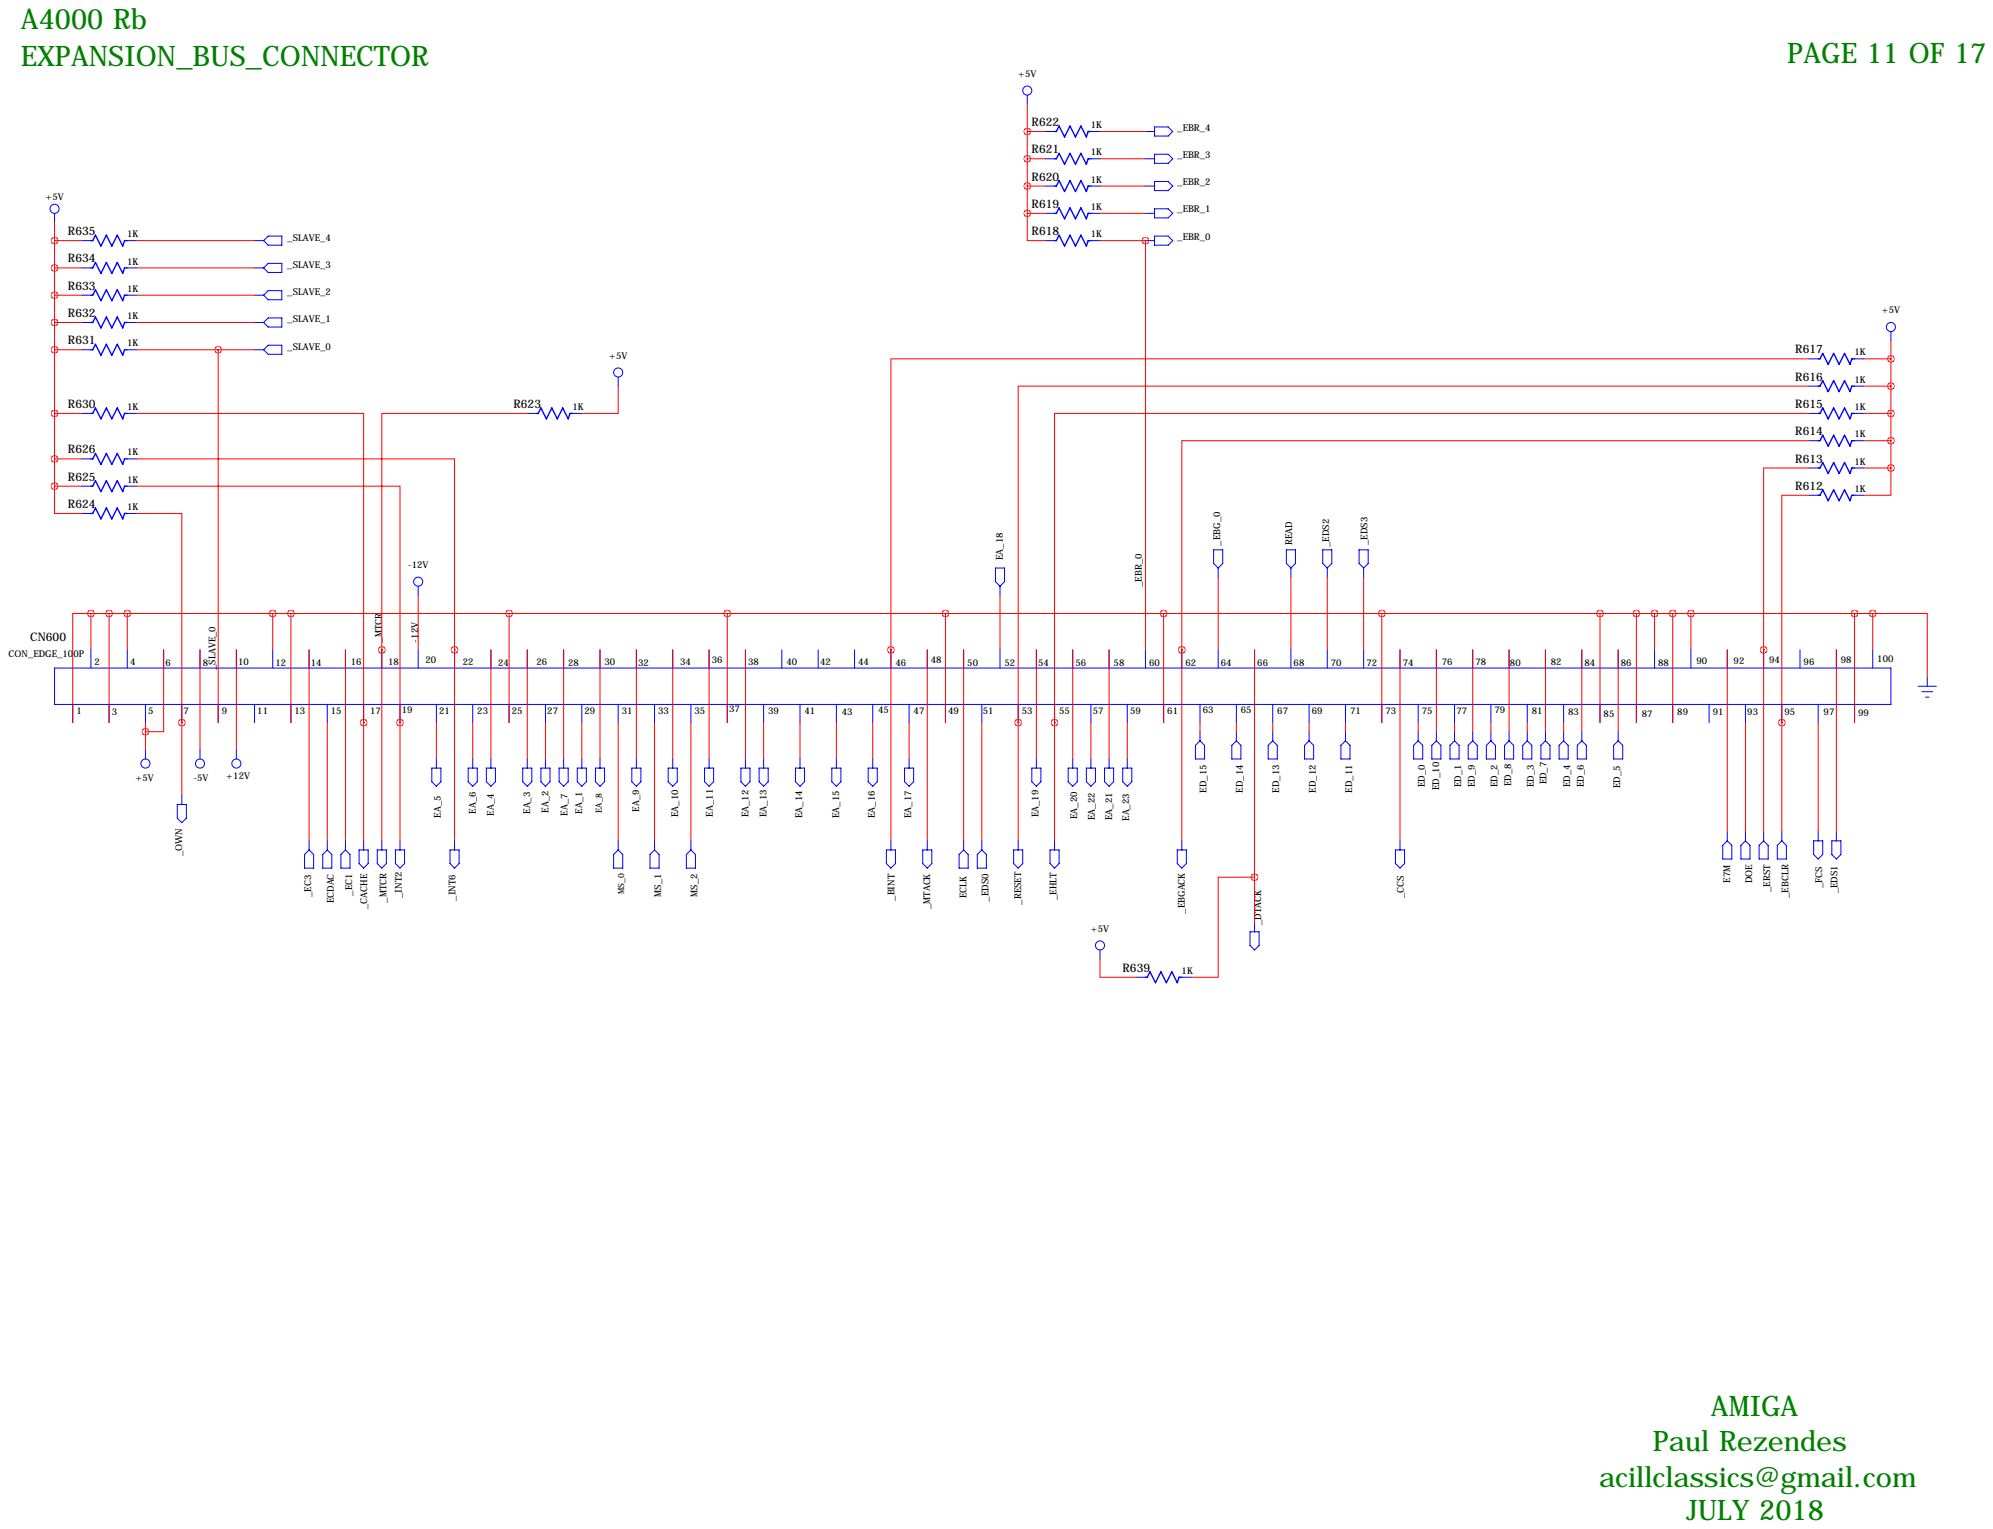
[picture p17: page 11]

# 32 BIT LOCAL SLOT

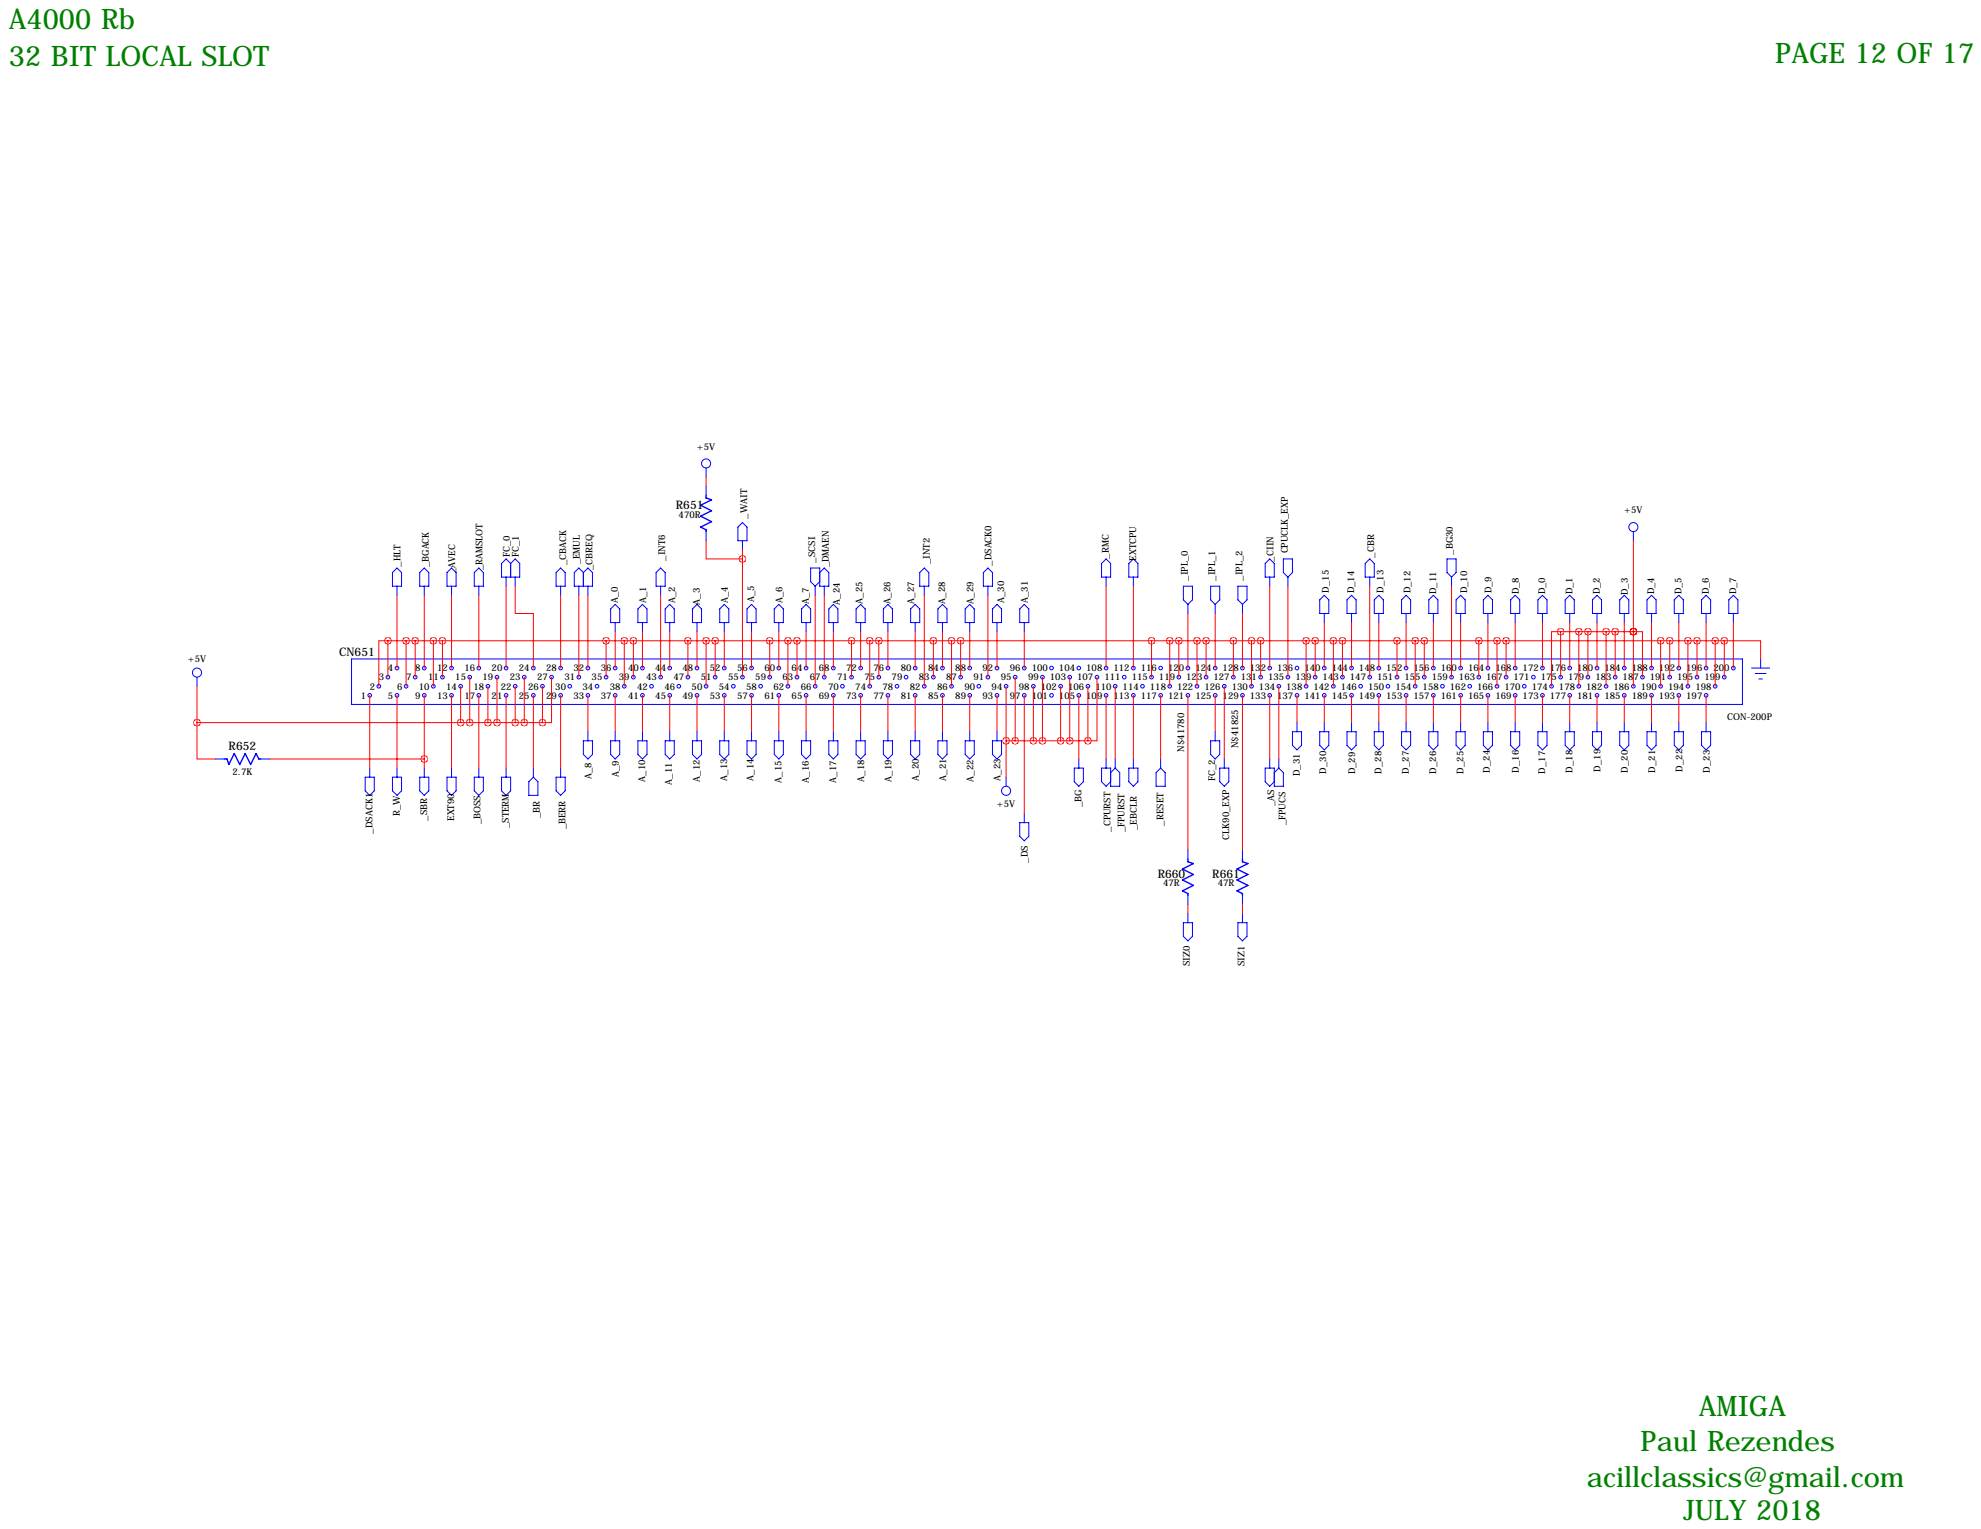
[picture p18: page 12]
CON-200P; _HLT; _AVEC; _DSACK1; _SBR; EXT90; _STERM; _CBREQ; _INT6; _WAIT; _SCSI; _DMAEN; _INT2; _DSACK0; EXTCPU; _CPURST; _EBCLR; _FPURST; _RESET; SIZ0; SIZ1; _BOSS; _FPUCS; _BERR _CBACK; _RAMSLOT; _EMUL; _BGACK; _RMC; CLK90_EXP; _CBR; CPUCLK_EXP; _CIIN; _IPL_0; _IPL_1; _IPL_2

# Fat Buster

U215-E


# FAST RAM PART A

# NOT INSTALLED


# FAST RAM PART B

A4000 Rb | PAGE 15 OF 17


# AT IDE Hard Disk Interface

A4000 Rb | PAGE 16 OF 17


# Mouse & Joystick connectors

A4000 Rb | PAGE 17 OF 17


5 D SOPT_3

11 SOPT_5 | | | 7 | 8

12 G SOPT_6 | | 9 | | 10

SOPT_7 | 11 | | | 12

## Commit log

2018-04-23 BOM OCR and corrections by tbtorro (Jozsef Vamosi) based on A4000 Service Addendum
    [A4000B_BOM.xls]
2018-04-23 Schematics (OLD) V1.37
    Original schematics prior to remake from reverse engineering and replica project. Used here for historical and comparisons.
2018-06-21 Add files via upload
    This is for review before telling the company doing the work on the layout to move forward! Please use the free PADS viewer and report anything you see that doesnt belong or is wrong. The company understands its not our job to review the work they do, but i feel we should provide some feedback before the final push to the end is started.
    [A4000_Rb-2x_RC1.sch]
2021-05-28 Delete A4000B_BOM.xls
    Out of date, and no longer valid.
    [A4000B_BOM.xls]
2021-05-28 Add files via upload
    Updated BOM. Thanks to Grim82!
    [Amiga_4000_BOM_JTv1.1.xlsx]
2024-05-15 New Gerbers with the updated silkscreens and pick and place files
    [A4000-Acill-Kavanoz-2-BOM.csv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]
2024-05-21 Add files via upload
    Alternative BOM but with no links to them for purchase. Several users wanted a cleaner BOM. Some changes made but nothing that will change builds over previous.
    [A4000B_BOM.xls]
2025-03-21 Update README.md
    Clarified making your own gerbers from project files
2026-04-18 Add files via upload
    Initial Kicad release project files. Created in the latest release of Kicad and tested as of April 2026.
2026-04-27 Add files via upload
    ASCII export from PADs. Tested good for import into Kicad and others. It is recommended you follow your preferred applications import guides for linking to board project file.
2026-04-27 Revise readme with ASCII export details
    Updated readme to reflect completion of ASCII export for schematics.
2026-04-27 Add files via upload
    Project and schematics
2026-04-27 Revise readme to clarify project archive contents
    Updated the readme to reflect project and schematics packaging.
